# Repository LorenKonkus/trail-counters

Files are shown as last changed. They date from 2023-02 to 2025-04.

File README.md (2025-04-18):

# trail-counters

Sooner or later, anyone involved in building hiking or mountain biking trails on public lands is faced with questions about their user community. Whether to justify more trails, improvement in existing trails, apply for grants or funding, understand usage patterns, or just bragging rights, everyone likes objective metrics. How many people are using their trails. When are they using it - are there peak times? Are there favorite loops that see a lot more use than other routes? You built it; did they come? 

Really good commercial trail counter systems are available from several companies. These packages are rugged, tested, and well supported but all that comes with a price. A recent survey found sensor prices ranging from $130 to $995 each, most designed as part of an overall system requiring the purchase of proprietary  hardware and ongoing software subscriptions for data collection and analysis from these sensors. If you've got the budget for this, there are several solid choices in that market. Go for it - read no further.

For the nonprofit trail advocacy groups I work with, an investment of a few thousand dollars to get started has always felt like a lot of money for just data. Stripped to its core, this is a simple task: detecting the presence of a user and recording that event in a time stamped log file. You don't need specialized analysis software. Standard spreadsheet programs are really good at crunching dates and times and making pretty graphs. Once you have event information you can import it and cut and slice it anyway that you'd like for presentation. You do need sensors and data collection hardware, but all the basic building blocks are readily available off the shelf and inexpensive, and that means you can use them in more places. You need to be very careful siting and securing a $500 sensor asset, but you can be a lot more casual about placing a $40 counter. 

That's the theme of this repository: removing the cost barriers by sharing ideas, hardware references, and code to make it easy to create low-cost trail counters for anyone who's interested in trail advocacy.

## Roadmap

The following overview documents might be useful:

- SensorOverview.md - an overview of the types of sensors commonly in use
- PackagingOptions.md - an overview of the ways I've packaged up hardware for field deployments
- HelpfulReferences.md - pointers to docs, videos, and commercial trail counter systems

Along this path, I've built several trail counters to test new ideas and refine the technology. These are:

- UnoCounter - an Arduino UNO based trail counter that records trail usaage event data on an SD card.
- ThriftyCounter - a minimal Adafruit M0 Adalogger feather based counter that records trail usage data on a microSD card. The primary goal was low power usage to minimize battery cost and size for extended unattended operation.
- NiftyCounter - a ThriftyCounter with a user interface based on the Adafruit ESP32-S2 Reverse TFT Feather. 
- NiftyCounterSTHS34PF80 - a NiftyCounter variant designed for an I2C based sensor. 

In addition to these trail counters, there's a small app that harvests trail usage information from Strava each day. Sometimes it's interesting to compare this information to actual counts, and it can be useful to gather information for more trail segments where it's impractical to host actual trail counters. Strava only tracks a small percentage of actual trail use, and so some sort of statistical local multiplier should be applied to get closer to true trail usage. 

- HarvestStrava - harvest segment usage data from Strava.

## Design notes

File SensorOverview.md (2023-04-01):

# Sensor Types

Sensor type and placement are the keys to accurate and correct counting of trail users. Commonly used sensors
are:
- Infrared
- Seismic
- Microwave
- Inductive Loop
- Ultrasound
- Pneumatic

Each has their advantages and disadvantages, but if you can obtain a logic level signal from a sensor when a trail user passes you can 
interface to it and count it.

It should be noted that none of these sensors is totally accurate. A sensor may not be able to distinguish between one hiker and two walking abreast. 
It may not be able to accurately count mountain bikers riding fast in a close cluster, as during a race event. Some sensors may be sensitive to 
the types of clothing being worn. A poorly placed sensor may count individual legs for footfalls. For these reasons, it's best to locate sensors in 
locations that minimize these potential errors:

- Place a sensor in a narrow constriction, as when a trail passes between two large trees or on a narrow bridge where traffic is naturally single file 
- Locate sensors after trail speed calming features, such as tight corners, narrow chicanes, or at the top of a steep climb to minimize issues with rapidly moving users
- Aim sensors at the torso of the typical trail user, not at head height or leg height

It may be possible to differentiate trail users based on sensor choice and positioning. For example, an active infrared sensor 8' off the ground would 
likely be tripped by an equestrian, but not a biker or hiker. An inductive loop would probably detect a bike, and maybe horseshoes, but not a hiker. 

When choosing a sensor strategy, one of the most important considerations will be power consumption. There are a number of really fine, accurate human presence
sensors but some of their power requirements make them really only suitable for line power applications or when large capacity batteries are employed.

## Active Infrared

to be written

## Passive infrared (PIR)

Passive Infrared sensors detect changes in received infrared radiation when a warm body, like a human or a horse, passes by the sensor. Since infrared 
radiation is light, these sensors can use lenses to control the range and detection area of a sensor.

These sensors are typically packaged as a group of one or more sensors and electronics that compares changes in the IR light detected by these sensors. Changes
are interpreted as motion and a digital logic output pulse is generated.

### Characteristics of PIR Sensors

- Because these sensors are detecting light, they must physically be open to the environment. Any environmental shielding must be transparent to IR radiation
- Many of the PIR sensors are wide field, intended for detecting movement within a room for instance. This is a consideration when siting, as we want to
detect only a single user at a time.
- PIR sensors can sometimes detect swaying branches, so try to site in an area away from shrubbery or low hanging branches that may be impacted by wind.
- PIR sensors can be overwhelmed by bright sunlight, and so try to site in an area with consistent shade. 
- Since PIR sensors do not requre emitting light or radiation, they can be much more energy efficient than active IR or microwave sensors.

### The HC-SR501 PIR Sensor

While there are many PIR sensors, this is a pretty convenient inexpensive package that is readily available. It includes a weatherproof IR transparent
shield (that conveniently fits in a 7/8" hole cut in an enclosure) and has potentiometers to control sensitivity and retrigger delay times. It's power efficient, requiring only about 50 ua and happily runs on either 5v or 3.3v sources so it's easy to power.

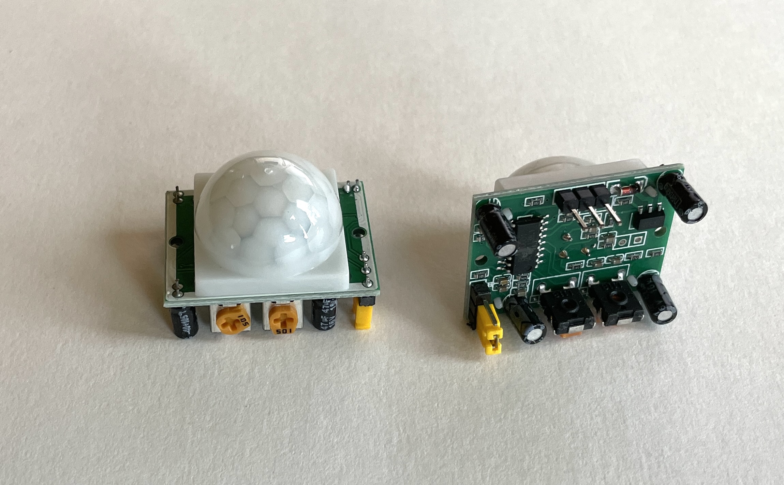
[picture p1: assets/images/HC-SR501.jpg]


I've found that setting the jumper for repeat triggering, the sensitivity to minimum, and the time delay to a minimum value yields the best results. Even then, the minimum time delay value may be too long for fast traffic. Still investigating. 

You can drill a 7.8 inch hole in a waterproof plastic enclosure so that the sensor lens is exposed to IR radiation while protecting the electronics and battery.

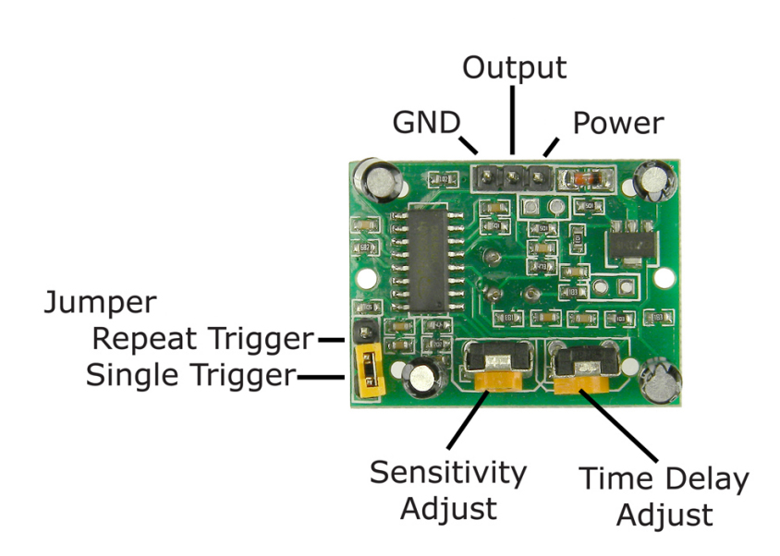
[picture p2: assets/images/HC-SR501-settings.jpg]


HC-SR501 sensors are available here: https://www.amazon.com/DIYmall-HC-SR501-Motion-Infrared-Arduino/dp/B012ZZ4LPM and at many other sources.
 
## Seismic

Seismic sensors work by sensing vibrations, and characterising how those vibrations may map to trail users. Seismic sensors are often mounted to structures 
such as bridges to detect footsteps.

### The LSM303AGR Sensor

The LSM303AGR chip is a low power, high sensitivity accelerometer and magnetometer package that has been used in a number of trail counter packages. 

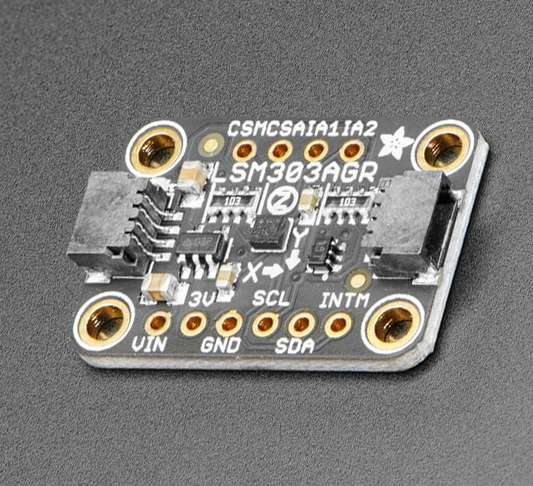
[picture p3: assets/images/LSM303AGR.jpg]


These modules are available from a number of sources. I'm using the breakout board available at https://www.adafruit.com/product/4413

(more coming soon as I gain more experience with it)

## Microwave

Microwave sensors work by broadcasting a low power microwave signal and listening for an echo. That signal is reflected strongly by water, and by 
happy coincidence humans are mostly water. Any change in the dopler shift of the received echo denotes movement, and movement and echo strength over a
certain level can be used to determine the presence of a nearby user. Sounds complicated, but all this has been figured out and bundled up in convenient 
inexpensive packages ready for use.

### Characteristice of microwave sensors

- Microwaves can pass through some solid materials such as wood. This means that a trail counter could be embedded inside a 4x4 wooden signpost next to a trail 
or located on the underside of a bridge plank and be complerely clandestine.
- Microwave sensors are affected by nearby metal, and so cannot be enclosed in a metal vandal resistent case or attached to a metal fencepost, for instance. 
- Microwaves seem less effective during rainstorms
- Microwave sensor operation is unaffected by bright sunlight, moving shadows, the darkness of night, or headlights on bikes.

### The RCWL-0516 sensor

This is a powerful yet inexpensive sensor, but a little hard to tune and senstive to surroundings. Tuning trigger and retrigger times means soldering SMD 
components. Still, it's my go-to for a microwave sensor. It's power efficient, requiring only about 1.2 ma and happily runs on either 5v or 3.3v sources so it's easy to power up in the field with batteries or solar. The output signal can be used directly as a logic input to a trail counter. 

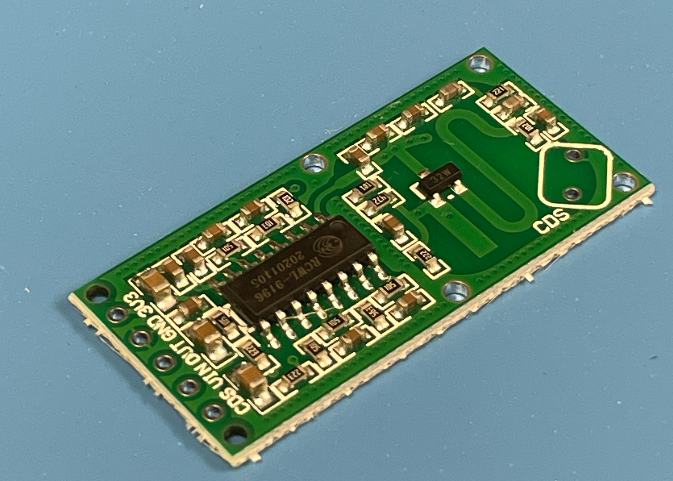
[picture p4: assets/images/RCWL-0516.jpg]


These modules are available at https://www.amazon.com/gp/product/B07YYY7J7D

There's alot of tuning and usage information at https://github.com/jdesbonnet/RCWL-0516 - see especially the issues discussions.

By default, these sensors have about an active high trigger time of 2 seconds and a low retrigger time of 2 seconds between detection events. This isn't optimal for detecting individual riders in a group of mountain bikers, so I generally modify these boards to lessen that. 

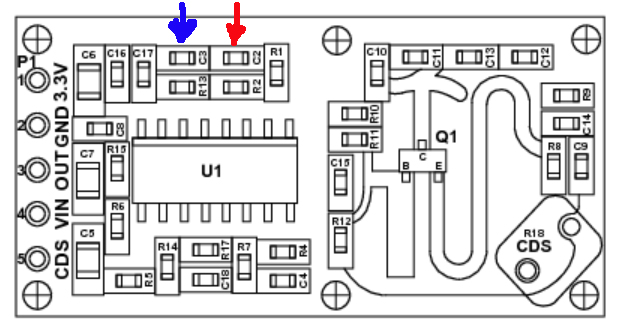
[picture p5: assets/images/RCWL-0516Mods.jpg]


You can replace C2 (in red) with a smaller capacitor for a narrower trigger pulse time and you can replace C3 (in blue) with a smaller capacitor for a shorter retrigger time between pulses. Replacing both with .001 uf results in a minimum output pulse duration of about 300 ms and a minimum time between pulses of about 300 ms which works pretty well differentiating fast moving bike traffic.

### The HFS-DC06F sensor

This is a really nice, stable sensor package with easily adjustable range and trigger time settings. The output signal can be used directly as an 
input to an Arduino Uno counter. The only downside to this package is that it's a bit of a power pig, requiring 30ma at 5 volts in operation. Given 
that, it does work well as a detection sensor if you turn down the range and trigger time settings to their minimal values. This will result in a workable range of about 6 feet and about 2 seconds of high signal for each detection event. This is fine for hikers and relatively slow low volume bike traffic where users are 4 seconds apart, but may undercount if they are closer together than that.

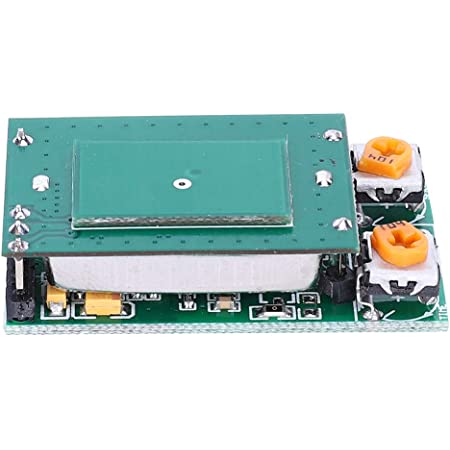
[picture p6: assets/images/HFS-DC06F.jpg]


These modules are currently available at https://www.amazon.com/gp/product/B08TMQ36H6 or shop around.

## Inductive Loop

to be written

## Ultrasound

to be written

## Pneumatic

to be written

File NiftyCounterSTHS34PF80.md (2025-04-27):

# NiftyCounterSTHS34PF80

NiftyCounterSTHS34PF80 is a derivitive of the NiftyCounter with code updated to work with an ST Microelectronics STHS34PF80 TMOS motion and presence sensor
on an I2C bus and separate interupt input. 
With this sensor, the Adafruit ESP32-S2 (or -S3) Reverse TFT Feather microcontroller waits for an interupt and then communicates with the sensor to determine 
presence or motion within its field of view, records each trail user detection event as an entry in a .CSV file on a 
microSD card that can be collected and imported into a spreadsheet. 

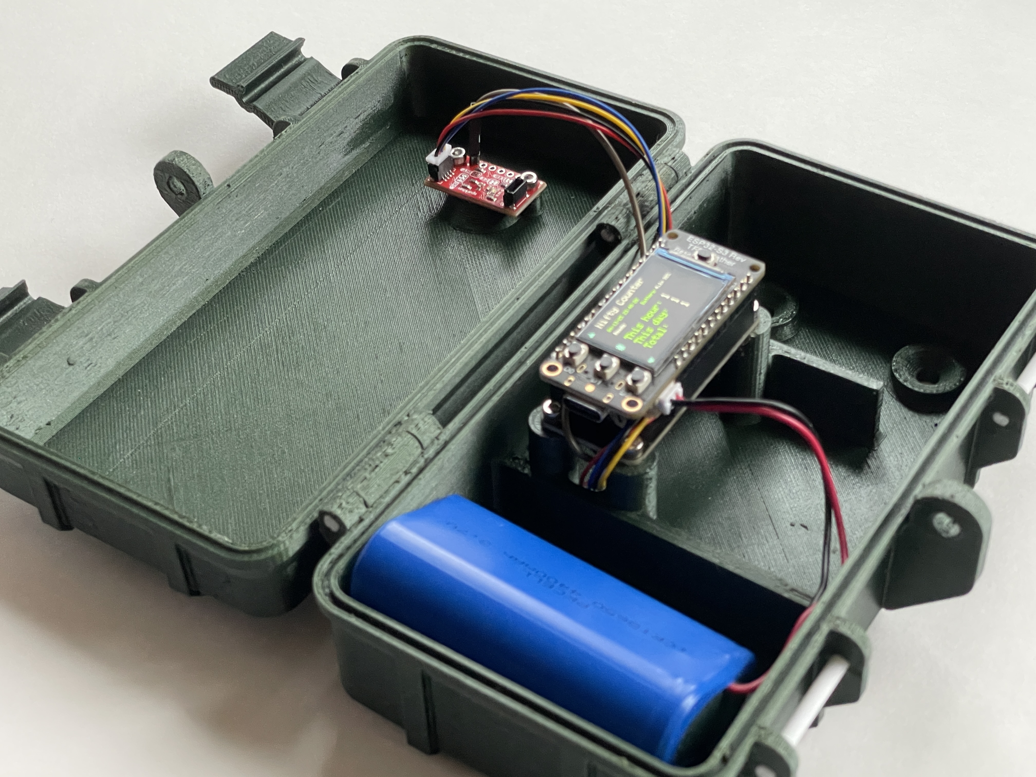
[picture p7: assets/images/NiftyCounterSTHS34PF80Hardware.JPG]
NiftyCounter assembled


## Hardware Platform

NiftyCounterSTHS34PF80 is based on an Adafruit ESP32-S2 Reverse TFT Feather board, available at https://www.adafruit.com/product/5345 Alternately, it seems to run just fine on the -S3 variant as well, so use whatever is available.

The Reverse TFT Feather board includes the processor, a nice 240x135 TFT display with three buttons, a LiPo battery charger, WiFi, and other features we don't need (and will keep turned off to save power). 
The ESP32-S2 on this board is different than the processor on the NiftyCounter board, but it too is supported by the Arduino IDE development environment
so it was pretty straightforward to migrate the NiftyCounter code to this platform. This processor has much more memory and processing power available, so there's
room to code up a nice user interface and expand features in the future.

Like the ThriftyCounter, the LiPo battery support on this board opens up a number of possibilities in power  management. If USB power is available, the adalogger board will 
automatically use that power source and charge an attached LiPo battery. If the USB power is lost, the adalogger board uses the LiPo battery as a source. 
This means you could use a cheap USB solar panel charger to power it during the day and keep the LiPo battery topped off, or periodically plug in an external USB
battery pack to top off an internal LiPo battery. Or just swap the LiPo battery when you're swapping the microSD card each month. 

In addition to the ESP32-S2 feather board we'll need to add data recording and a battery backup real time clock. Adafruit has one of these at
https://www.adafruit.com/product/2922 that works nicely and can stack on the Reverse TFT Feather Board

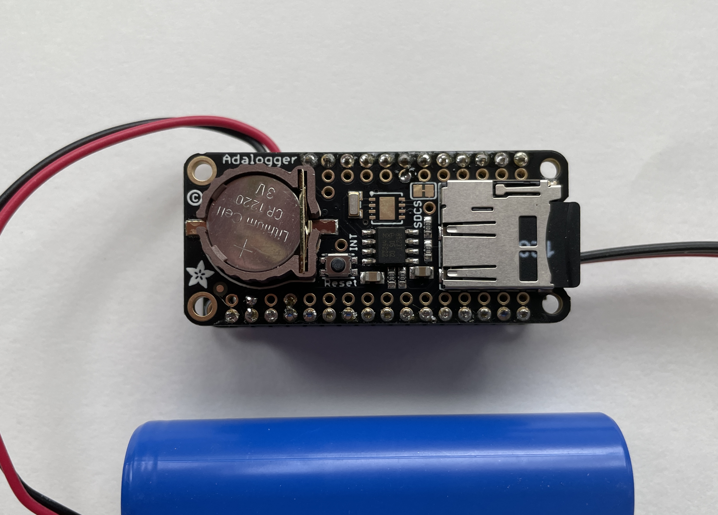
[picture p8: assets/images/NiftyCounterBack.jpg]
NiftyCounter assembled


As I mentioned, the ESP32-S2 contains WiFi support, and the -S3 variant includes BLE as well. It would be possible to enable one of these and remote harvest
counter data without touching a counter, but there's two big issues with this:
- Power consumption.
- Counter Discovery. Broadcasting a signal makes a counter huntable by nefarious foreign agents.

It would be possible to code a button or menu option to turn on communications for a short period to harvest data, but that means having access to the counter and if 
you're there it's so much easier to just swap the microSD card. 

## Software Platform

The NiftyCounterSTHS34PF80 software can be found in NiftyCounterSTHS34PF80.ino in this repository. Well, it will be as soon as I'm happy enough 
with the software to share.

## Sensor

The NiftyCounterSTHS34PF80 software was designed for the ST Microelectronics STHS34PF80 TMOS motion and presence sensor, available at https://www.sparkfun.com/sparkfun-mini-human-presence-and-motion-sensor-sths34pf80-qwiic.html

See [Sensor Overview](SensorOverview.md) for more information on sensors.

## Using the NiftyCounterSTHS34PF80

On startup, the display, clock, and SD card are initialized and readied. Users can follow along on the startup log

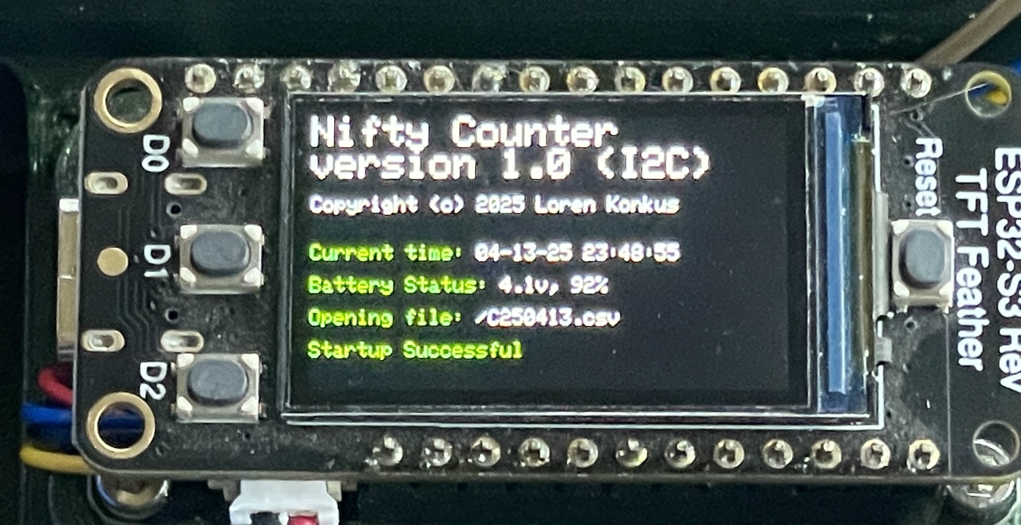
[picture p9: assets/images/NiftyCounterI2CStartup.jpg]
NiftyCounter assembled


After a moment or two, the normal main dashboard is displayed. This dashboard includes information about the current time, battery status, sensor status, and count
values for the hour, day, and since last startup.

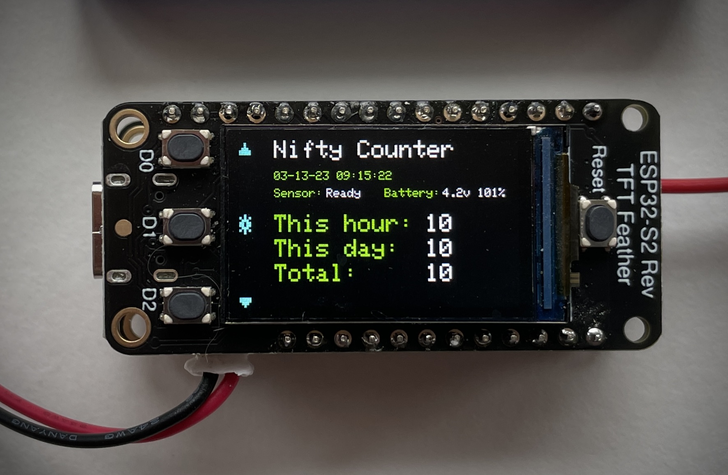
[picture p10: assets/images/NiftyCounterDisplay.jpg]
NiftyCounter assembled


The display remains visible for a few moments, and then is turned off to save power. Pressing any button on the left will reactivate the display again. 

Pressing the middle (D1) button will display the options menu:

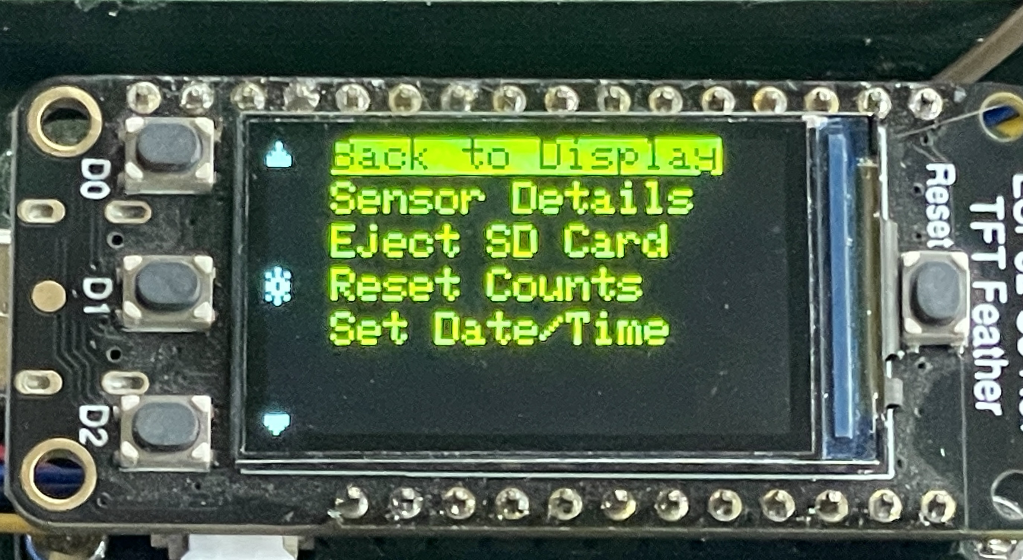
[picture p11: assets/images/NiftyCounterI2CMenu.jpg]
NiftyCounter assembled


These menu options can be used to select various features - debugging sensors, safely ejecting the microSD card, etc. D0 is the up button, D2 the down button, and D1
selects/enters. 

Selecting the Sensor Details menu option will display a dynamic page displaying position and motion sensor values. Highlighted reverse text indicates that the values are at the level
that would be considered "active":

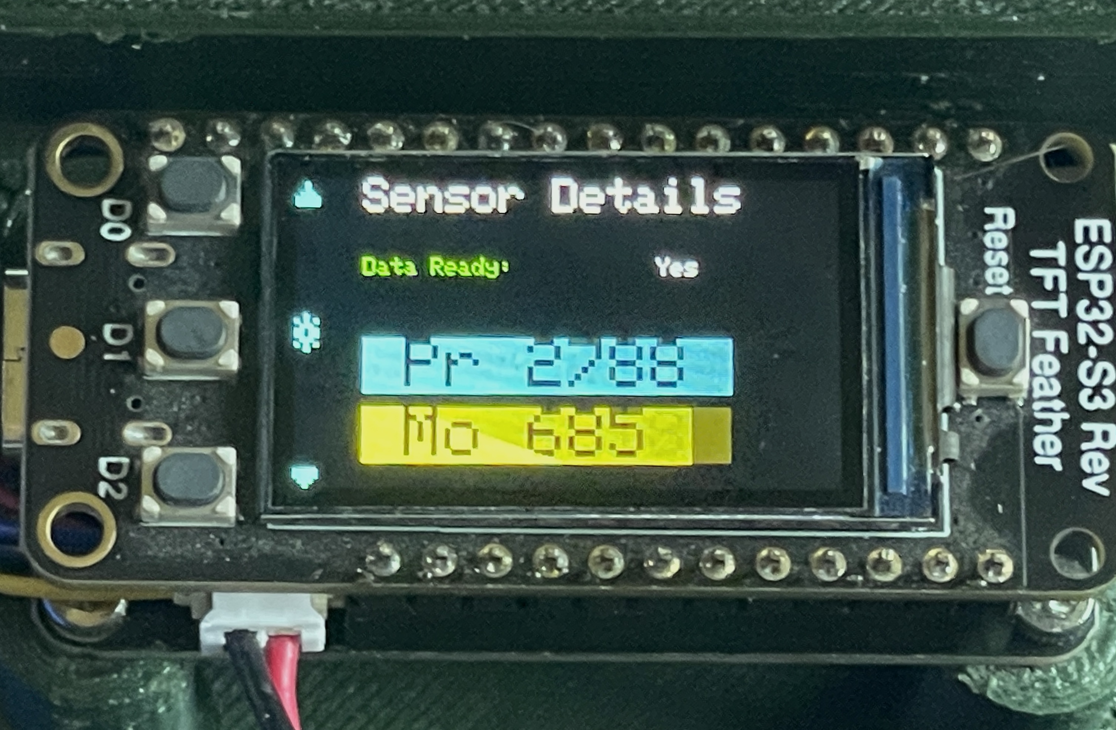
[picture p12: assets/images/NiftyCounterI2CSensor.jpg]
NiftyCounter assembled


To harvest data, simply select "eject SD card" in the menu, replace the microSD card with a new, preformatted card and press the board Restart button. The SD 
card will contain a .csv file named "CYYMMDD".csv, where YYMMDD reflect the current date. Each entry in the csv file will contain fields for the timestamp of 
the event, the date of the event, the time of the event, the duration of the event, and an event count.

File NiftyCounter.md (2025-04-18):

# NiftyCounter

NiftyCounter is an Adafruit ESP32-S2 (or -S3) Reverse TFT Feather based trail counter that records each trail user detection event as an entry in a .CSV file on a 
microSD card that can be collected and imported into a spreadsheet. 

NiftyCounter was developed as a followup to the ThriftyCounter project. ThriftyCounter works pretty well and has been counting trail users for some time, but there
was room for improvement.

- There's no way to determine if someone is looking at it or not, and so the green LED is faithfully lit every time a user detection sensor is active. This takes
about 11 ma the entire duration that a user is present. It's not a lot, but it adds up over time. 
- It's an act of faith that the RTC clock battery is good and the date and time is correct when you deploy a counter
- There's no way to determine that the LiPo battery is low and needs to be replaced or recharged

As it turns out, for only an additional $10 or so you can add a very nice user interface to this design, and a user interface can address each of these
shortcomings. Hence, the NiftyCounter was created.

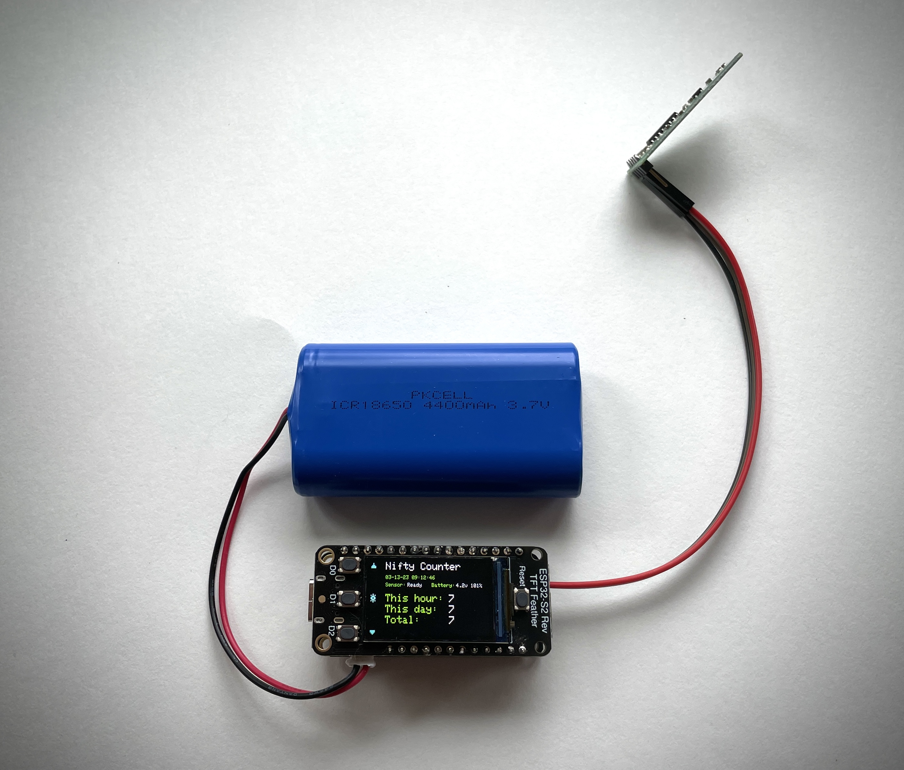
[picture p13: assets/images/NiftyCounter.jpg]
NiftyCounter assembled


## Hardware Platform

NiftyCounter is based on an Adafruit ESP32-S2 Reverse TFT Feather board, available at https://www.adafruit.com/product/5345 Alternately, it seems to run just fine on the -S3 variant as well, so use whatever is available.

The Reverse TFT Feather board includes the processor, a nice 240x135 TFT display with three buttons, a LiPo battery charger, WiFi, and other features we don't need (and will keep turned off to save power). 
The ESP32-S2 on this board is different than the processor on the NiftyCounter board, but it too is supported by the Arduino IDE development environment
so it was pretty straightforward to migrate the NiftyCounter code to this platform. This processor has much more memory and processing power available, so there's
room to code up a nice user interface and expand features in the future.

Like the ThriftyCounter, the LiPo battery support on this board opens up a number of possibilities in power  management. If USB power is available, the adalogger board will 
automatically use that power source and charge an attached LiPo battery. If the USB power is lost, the adalogger board uses the LiPo battery as a source. 
This means you could use a cheap USB solar panel charger to power it during the day and keep the LiPo battery topped off, or periodically plug in an external USB
battery pack to top off an internal LiPo battery. Or just swap the LiPo battery when you're swapping the microSD card each month. 

In addition to the ESP32-S2 feather board we'll need to add data recording and a battery backup real time clock. Adafruit has one of these at
https://www.adafruit.com/product/2922 that works nicely and can stack on the Reverse TFT Feather Board

NiftyCounter assembled

As I mentioned, the ESP32-S2 contains WiFi support, and the -S3 variant includes BLE as well. It would be possible to enable one of these and remote harvest
counter data without touching a counter, but there's two big issues with this:
- Power consumption.
- Counter Discovery. Broadcasting a signal makes a counter huntable by nefarious foreign agents.

It would be possible to code a button or menu option to turn on communications for a short period to harvest data, but that means having access to the counter and if 
you're there it's so much easier to just swap the microSD card. 

## Software Platform

The NiftyCounter software can be found in NiftyCounter.ino in this repository.

## Sensor

See [Sensor Overview](SensorOverview.md) for more information on sensors.

I used RCWL-0516 microwave sensors when using this trail counter. These sensors can be powered directly from the board (using the GND and 3.3V pins 
and the output logic signal can be tied to one of the input pins (I used DIO 11 in the software). This sensor works best when located a couple inches 
away from the feather boards and battery, with no metal or electronics directly in front or behind the antenna area on the sensor board.

The data sheets for the RCWL-0516 say that the board requires an input voltage between 4 and 28v, but that input is regulated to 3.3 volts to run board and the
samples that I've used seem totally happy running with the nice, clean, regulated 3.3v source that the adalogger feather can provide.

## Using the NiftyCounter

On startup, the display, clock, and SD card are initialized and readied. Users can follow along on the startup log

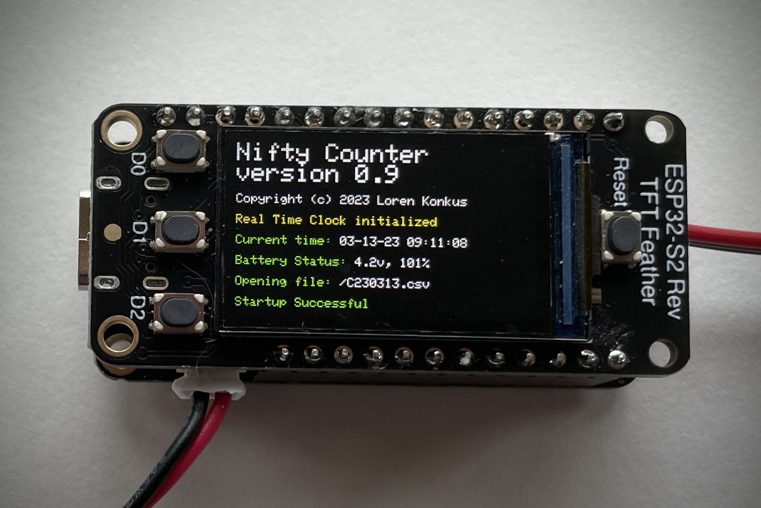
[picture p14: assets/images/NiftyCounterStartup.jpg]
NiftyCounter assembled


After a moment or two, the normal main dashboard is displayed. This dashboard includes information about the current time, battery status, sensor status, and count
values for the hour, day, and since last startup.

NiftyCounter assembled

The display remains visible for a few moments, and then is turned off to save power. Pressing any button on the left will reactivate the display again. 

Pressing the middle (D1) button will display the options menu:

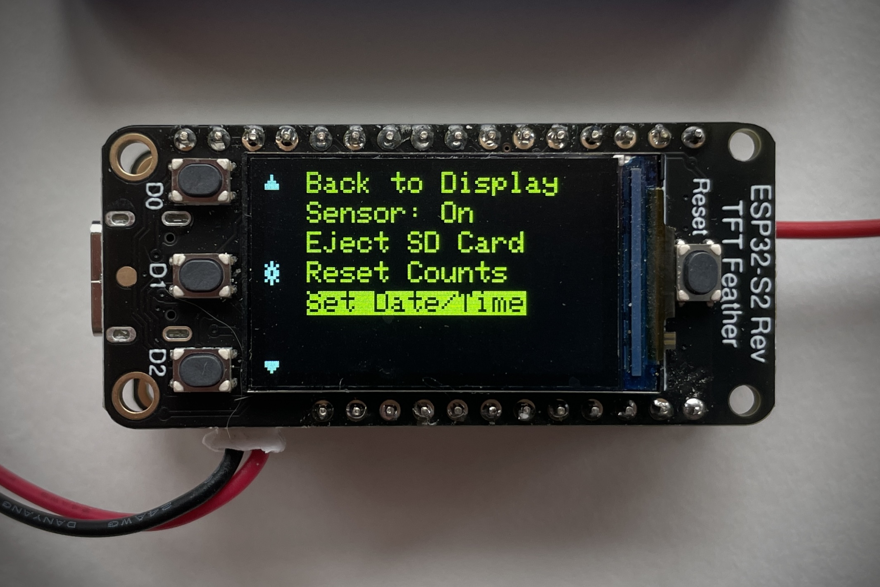
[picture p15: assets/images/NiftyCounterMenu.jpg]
NiftyCounter assembled


These menu options can be used to select various features - disabling sensors, safely ejecting the microSD card, etc. D0 is the up button, D2 the down button, and D1
selects/enters. 

To harvest data, simply select "eject SD card" in the menu, replace the microSD card with a new, preformatted card and press the board Restart button. The SD 
card will contain a .csv file named "CYYMMDD".csv, where YYMMDD reflect the current date. Each entry in the csv file will contain fields for the timestamp of 
the event, the date of the event, the time of the event, the duration of the event, and an event count.

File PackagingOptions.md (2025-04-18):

# Packaging Options

Here are several alternatives I've used for packaging a counter:

- ZipLoc Bag
- ABS Waterproof Box
- 3d Printed Enclosures

## ZipLoc Bag

The simpliest option when deploying a trail counter is to tuck it in a simple ZipLoc bag. These are waterproof, low cost, and easy to locate in small, odd areas. 
Bags are great for quickly deploying a prototype out on the trail. 

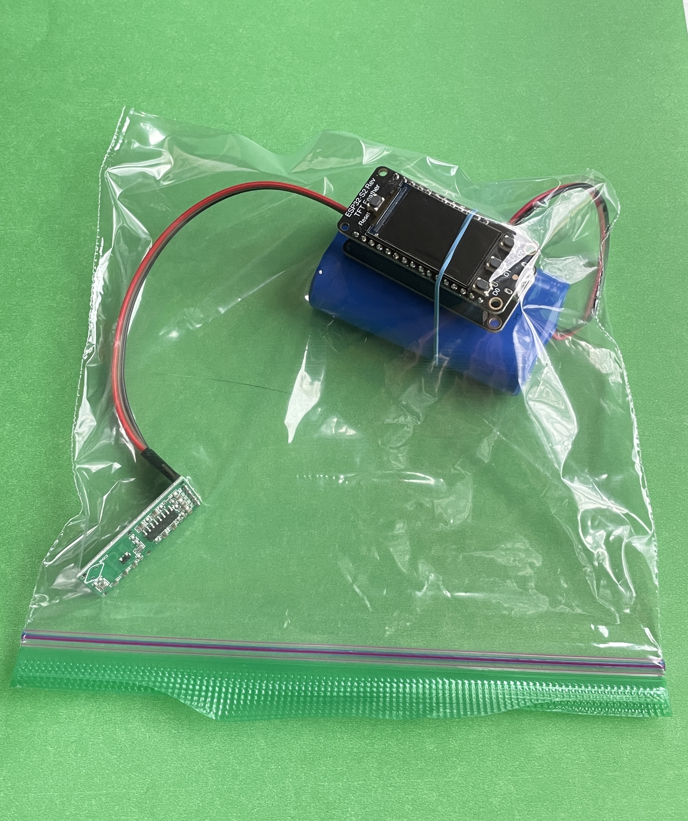
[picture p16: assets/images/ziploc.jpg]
ziploc


On the downside, they aren't particularly robust, are vulnerable to animals, and may be mistaken as rubbish. Some sensors are very sensitive to their surroundings
and may be affected by batteries and controller locations, and that's hard to control in a bag. 

## ABS Waterproof Box

Commercial ABS waterproof junction boxes are solid and robust and available in many sizes and formats. Here's one that I've used.

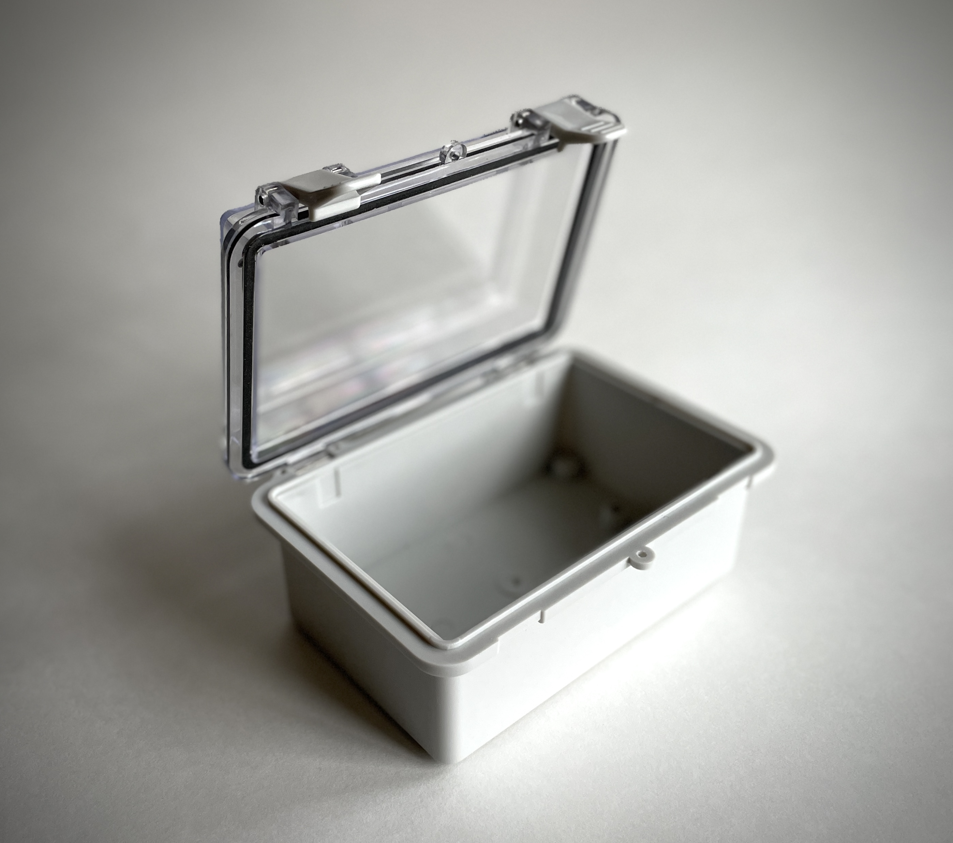
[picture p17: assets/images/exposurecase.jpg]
case


This is relatively small at 6"x4"x3" but sill big enough for an Arduino Uno and is available at https://www.amazon.com/Zulkit-Waterproof-Electrical-Transparent-150x100x70/dp/B07RPNWD47

Being ABS, it's easy to use styrene solvent to glue plastic standoffs wherever needed to mount a circuit board.

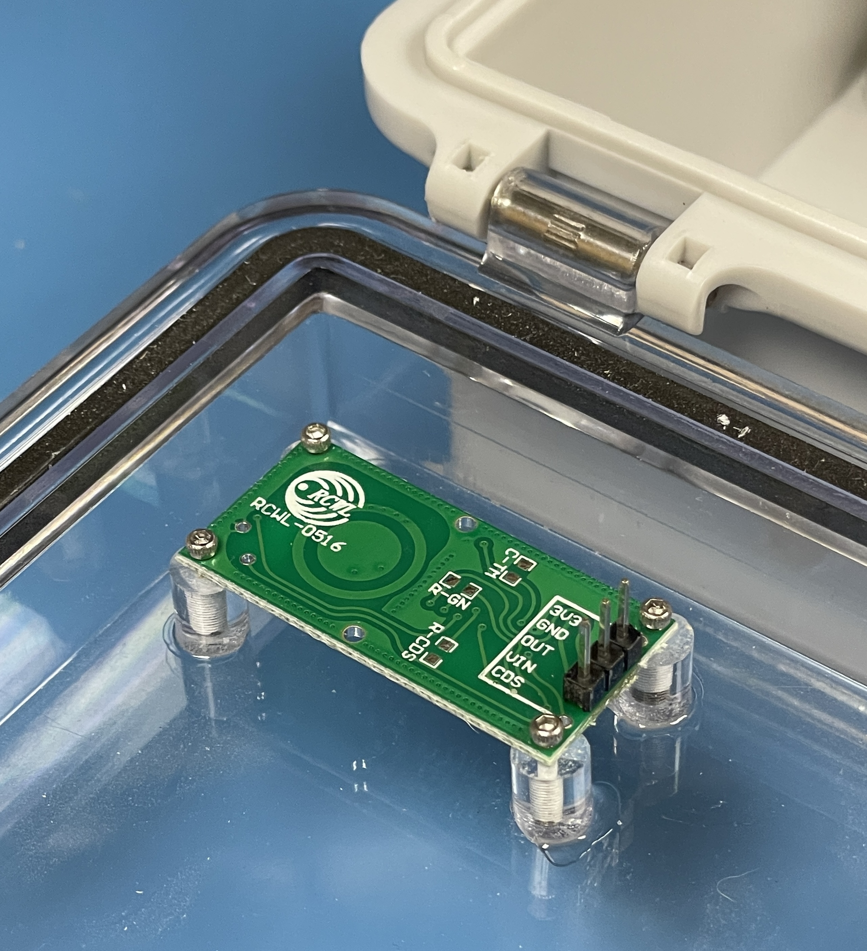
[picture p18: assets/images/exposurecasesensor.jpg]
case

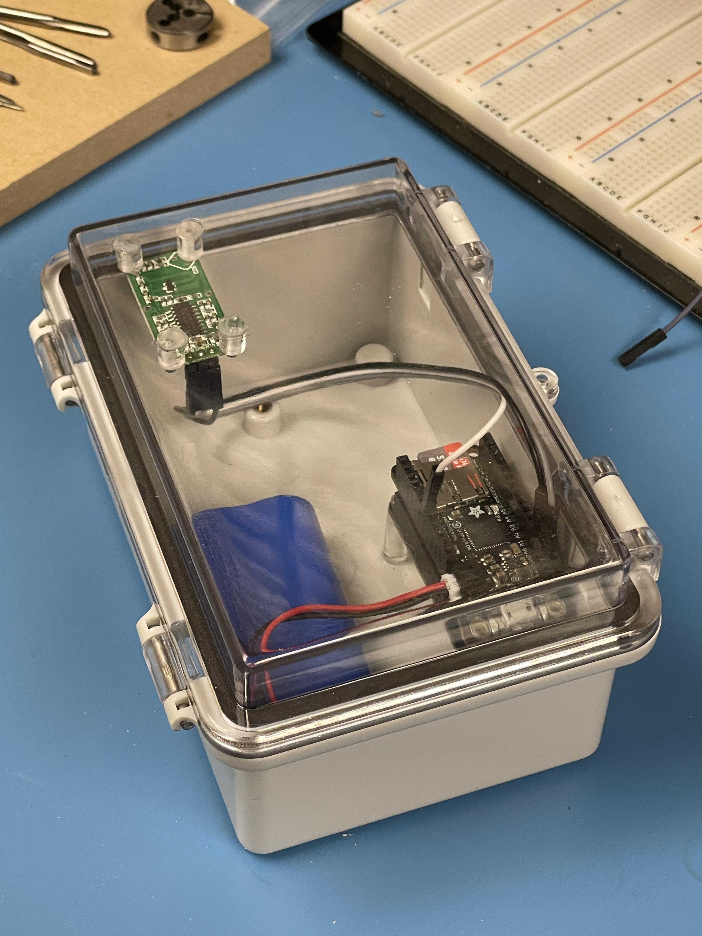
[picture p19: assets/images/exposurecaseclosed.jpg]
case


If you have a transparent cover for the box, boards can be positioned so that LEDs are easily visible to confirm operation after positioning.

If you're using a microwave sensor that can sense presence through wood, one of my favorite placements is on a support beam under a bridge. Narrow bridges encourage
users to pass single file and at relatively slow speeds and help to ensure accurate counts.

case

## 3d Printed Enclosures

### PostIt Frame

The PostIt frame was designed to conceal a feather based trail counter within a 2 inch diameter, 8 inch deep hole bored into a wooden post. 4x4 posts are common
sights along a trail, often festooned with decals and pointers, and are not obvious targets for anyone looking for a trail counter. This design relies on the 
post for environmental protection, and can only be used with sensors that can detect presence through wood (like a microwave sensor). 

case

The basic design is a cylinder with space for a 4400 mah LiPo battery at the bottom, a stack of two feather boards, and space for a sensor at the top. It's open to allow access 
to the front and back of a feather stack to replace the battery, plug in a USB cord, and swap microSD cards without removing any boards from the frame. There's a 
recess for a rubber band to hold the battery at the bottom, and a finger hold at the top to ease extraction from a post. (Or you can tie a lanyard to it so it's easier to retrieve from a deeper bore.) The cylinder is 1.75 inches in diameter which provides lots of clearance in a 2 inch bore in a post. 

This frame can hold components for either the ThrifyCounter or NiftyCounter. Here's what it looks like with NiftyCounter components mounted:

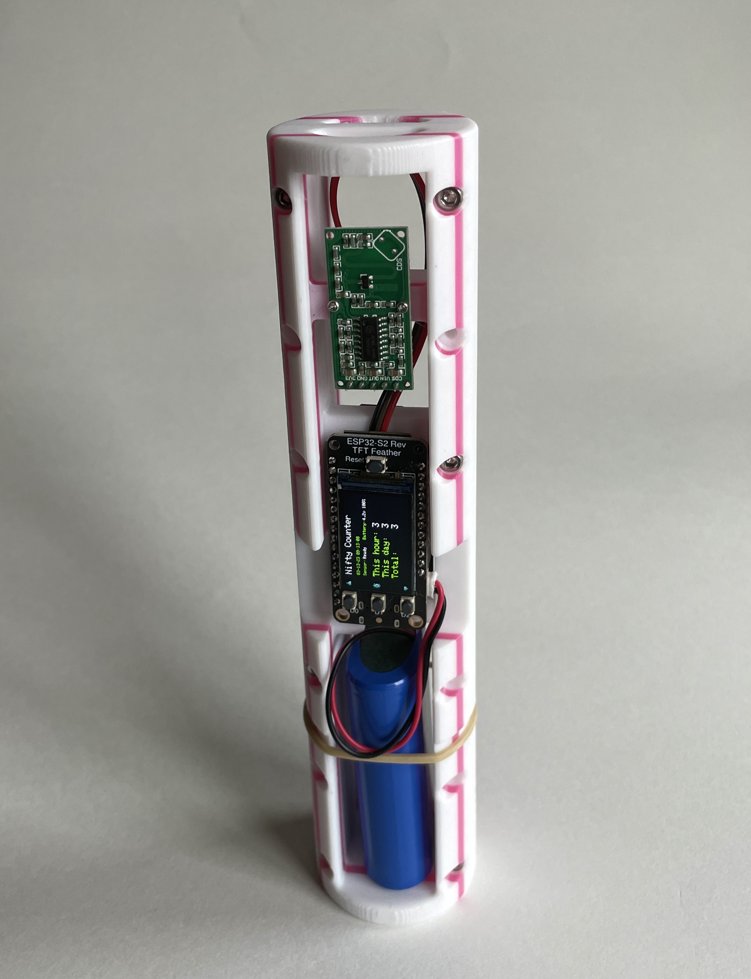
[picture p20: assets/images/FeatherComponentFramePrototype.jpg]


The STL file for the PostIt frame can be found in the repository at PostIt.stl. When 3d printing, it's easiest to print in two sections, front and back, to eliminate
issues with horizontal spans and avoid the need for bridging or supports. These sections can either be glued together or assembled using 2.5 mm machine screws. 
You can find a two part version at PostItSplit.stl. 

The model has tap holes for a RCWL-0516 microwave sensor (mount with 1.4 mm machine screws) and tap holes for feather boards (mount with 2.5 mm machine screws). You
might need to tweak this somewhat when using different sensors.

### NiftyCase Box

The NiftyCase box was designed to house a feather stack, some sort of infrared or visual detector, and a battery in a case that could be screwed to a 4x4 post or a tree. 

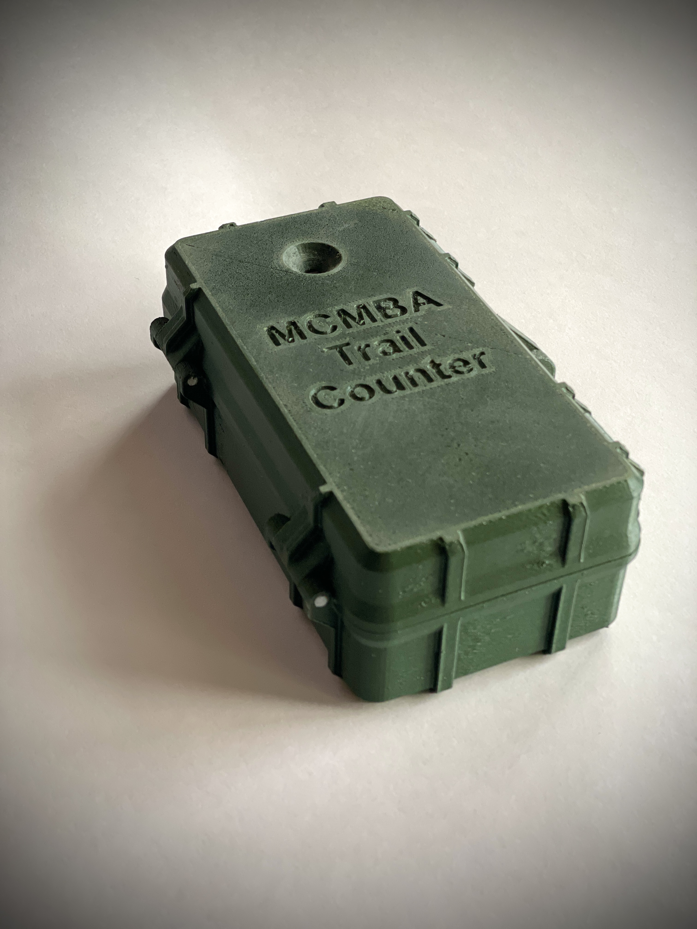
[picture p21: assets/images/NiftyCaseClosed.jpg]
case

case

This frame can hold components for either the ThrifyCounter, NiftyCounter, or NiftySTHS34PF80. Here's what it looks like with NiftySTHS34PF80 components mounted:

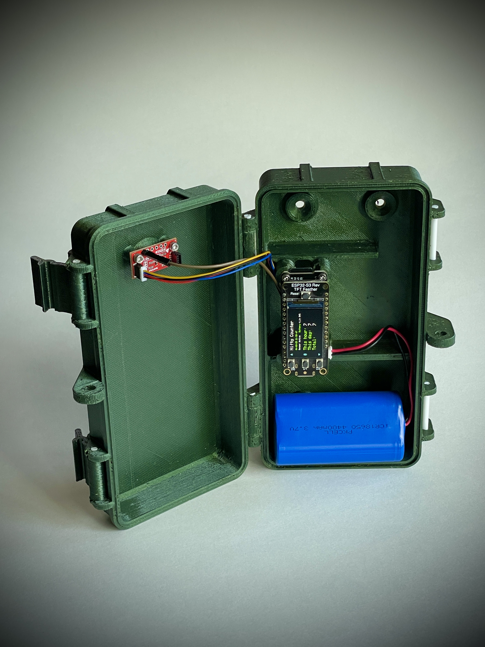
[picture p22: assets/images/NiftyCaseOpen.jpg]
case


There's plenty of space reserved for larger batteries.

The STL files for this can be found in the repository as NiftyCaseBox.stl, NiftyCaseLid.stl, NiftyCaseLatch.stl (two required) and NiftyCaseTPUSeal. Since these are exposed to the elements, select an appropriate material such as PETG or ABS for longevity. The NiftyCaseTPUSeal is an optional flexible gasket that helps to make the box more weathertight, and should be printed in something like TPU. 

## Tagging

Regardless of what package you use, it's good practice to include your name (or your organization's name) and a contact phone number in the package. If the 
package is misplaced, this information may help it find its way home. If it's located by a suspicious individual, a phone call can help the bomb squad determine that 
it's a LiPo battery and not C4.

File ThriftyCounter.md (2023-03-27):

# ThriftyCounter

ThriftyCounter is an AdafruitFeather M0 Adalogger based trail counter that records each trail user detection event as an entry in a .CSV file on a 
microSD card that can be collected and imported into a spreadsheet. ThriftyCounter was developed as a followup to the UnoCounter project in an attempt to 
lower energy usage and improve battery life. An Arduino Uno requires a fair amount of power even when the microcontrolleris in sleep mode, and this
has an impact on the battery required for extended deployment times out in a forest. Batteries are expensive, and if we can halve or quarter the amount
of capacity that we need we can reduce the cost significantly. ThriftyCounter was a great step in that direction. 

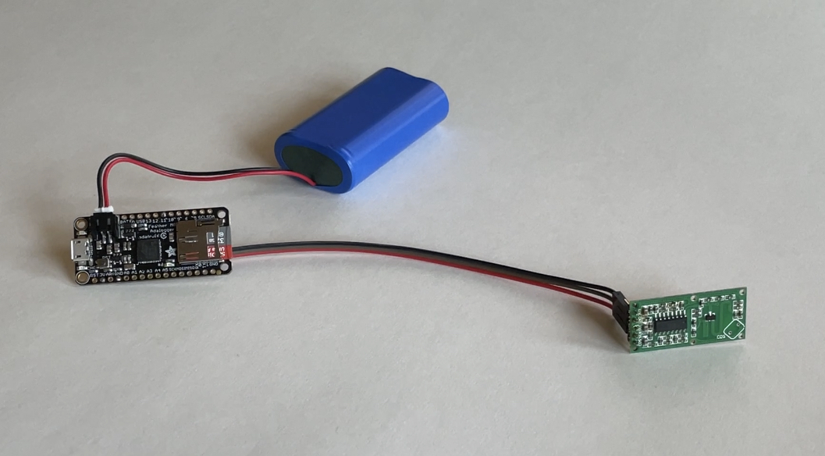
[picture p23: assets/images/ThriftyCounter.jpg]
ThriftyCounter assembled


## Hardware Platform

ThriftyCounter is based on an Adafruit Feather M0 Adalogger board, available at https://www.adafruit.com/product/2796 

In the same way that there's an ecosystem for Arduino Uno boards and shields that add additional capabilities, there's an ecosystem of Feather boards and "wings"
that stack and add capabilities. 

The adalogger board includes the processor, a LiPo battery charger, and a microSD card slot, so it has most of what we need (except a good real time clock - more on that
later). The ARM M0 processor on this board is different than the processor on the Uno board, but it is supported by the Arduino IDE development environment
so it was pretty straightforward to migrate the UnoCounter code to this platform. This processor has more memory and processing power available, and so there's
room to grow if we want to, say, enhance the software to collect data from multiple sensors.

The LiPo battery support on this board opens up a number of possibilities in power  management. If USB power is available, the adalogger board will 
automatically use that power source and charge an attached LiPo battery. If the USB power is lost, the adalogger board uses the LiPo battery as a source. 
This means you could use a cheap USB solar panel charger to power it during the day and keep the LiPo battery topped off, or periodically plug in an external USB
battery pack to top off an internal LiPo battery. Or just swap the LiPo battery when you're swapping the microSD card each month. 

One thing the adalogger board doesn't have is a good real time clock, or RTC. The M0 processor provides an RTC and the software is able to use it as a backup
time source, but any information about the current date and time is lost 
whenever power is lost or the reset button is pressed. Fortunately, there are plug in feather wings that adds a battery backed up RTC. I've used one based on
the DS3231 chip, available at https://www.adafruit.com/product/3028 Plug this wing into the adalogger feather, and it keeps excellent track of date and times 
across battery changes, restarts, and so forth. 

## Software Platform

The ThriftyCounter software can be found in ThriftyCounter.ino in this repository.

## Sensor

See [Sensor Overview](SensorOverview.md) for more information on sensors.

I used RCWL-0516 microwave sensors when using this trail counter. These sensors can be powered directly from the board (using the GND and 3.3V pins 
and the output logic signal can be tied to one of the input pins (I used DIO 11 in the softwear). This sensor works best when located a couple inches 
away from the feather boards and battery, with no metal or electronics directly in front or behind the antenna area on the sensor board.

The data sheets for the RCWL-0516 say that the board requires an input voltage between 4 and 28v, but that input is regulated to 3.3 volts to run board and the
samples that I've used seem totally happy running with the nice, clean, regulated 3.3v source that the adalogger feather can provide.

## Using the ThriftyCounter

This counter has a very minimal user interface that leverages the green and red LEDs on this board on the controller board.

Upon startup, either by inserting a battery or pressing the restart button, the software boots up and attempts to write to the
microSD card. Red LED flashes indicate an issue during startup:

-  2 blinks = error, no RTC clock found
-  3 blinks = error, no microSD card. Insert a FAT32 formatted card to clear condition
-  4 blinks = error, unable to write to a microSD card

After startup, the green LED on the feather is lit whenever the detection sensor is high. The red LED flashes once each time an event
is written to the SD card. Because writing to the SD card is energy intensive, several events may be buffered and written together. 

To harvest data, simply replace the microSD card with a new, preformatted card and press the restart button. The SD card should contain a .csv file
named "CYYMMDD".csv, where YYMMDD reflect the date that the counter was started. Each entry in the csv file will contain fields for the timestamp of the event, the date of the event, the time of the event, the duration of the event, and an event count. 

There's no provision for setting the date and time on the counter. Date and time are updated when the software is downloaded into the controller. The clock should keep accurate time throughout the life of the clock coin battery cell, which should be at least a couple years. At that point, you'll have to change the clock battery and re-load the software again.

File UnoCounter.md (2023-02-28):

# UnoCounter

UnoCounter is a simple an Arduino Uno based trail counter that records each trail user detection event as an entry in a .CSV file on 
an SD card that can be collected and imported into a spreadsheet. It's the first trail counter that I built and deployed to validate the
core project principle: using inexpensive off the shelf hardware components to build a workable counter. And it worked - you can build
this counter by simply plugging things together. 

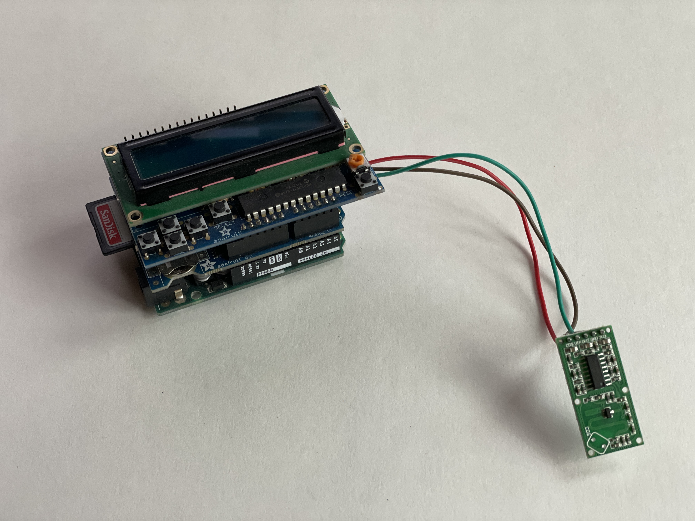
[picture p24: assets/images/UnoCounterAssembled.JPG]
UnoCounter assembled


## Hardware Platform

Ardunino Uno is a ubiquitous platform that is available from many different suppliers and supported by lots of STEM educational kits,
so it makes a good platform for getting started with this technology since you can ask any kid in your local school's robotics club 
for help if you get into trouble. Details on all this can be found at
https://www.arduino.cc/ and there are many really good youtube videos to peruse.

UnoCounter is based on a standard Arduino Uno R3 board and the Arduino IDE development environment. The Uno board contains the microcontroller 
and is where all the software needed to create a trail counter runs. Several companies sell clones of this board or you can buy them on the
arduino site. The official Arduino boards may cost a few dollars more, but helps to support the whole open source infrastructure around this 
technology.

The Arduino Uno ecosystem is populated by a host of supporting "shield" components that can be plugged into, or "stacked" on top of an 
Uno board. One of these shields provides nearly everything we need to support a trail counter: the Adafruit Data Logger shield for Arduino, 
available at https://www.adafruit.com/product/1141  

The Data Logger shield adds two key capabilities to the counter: a Real Time Clock to keep track of the date and time, and a SD card interface
that is used to record events to an SD card which can then be harvested and read by a laptop or computer.

In addition, the UnoCounter software supports an additional shield: an LCD Display Shield, available at https://www.adafruit.com/product/772
If present, this shield adds a handy user interface for testing and verifying your sensor  operation and setup, but really doesn't add any
value to the core mission - logging user detection events - and can be omitted. 

That's it, aside from a battery and a detection sensor. 

UnoCounter Boards

Internally, Arduino Uno boards operate on a 5V supply. You can use any battery capable of providing between 5 and 12 volts to power the stack, 
but the simple linear voltage regulators on these boards aren't terribly efficient and you'll get the best battery life at 5 volts. I've had 
best results with arrays of 4 1.2 volt rechargable NiMH cells. 

## Software Platform

The UnoCounter software can be found in UnoCounter.ino in this repository. 

## Sensor

See [Sensor Overview](SensorOverview.md) for more information on sensors.

I've typically used RCWL-0516 microwave sensors when using this trail counter. These sensors can be powered directly from the board (using the GND and 5V pins 
and the output logic signal can be tied to one of the input pins (I used DIO 3 in the softwear). This sensor works best when located a couple inches 
away from the arduino boards and battery, with no metal or electronics directly in front or behind the antenna area on the sensor board.

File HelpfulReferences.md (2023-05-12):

# Helpful References

A collection of references to documentation and educational materials related to trail counters.

## Trail Counter Education

### American Trails Webinar: Building a Comprehensive Count Program in Your Park or on Your Trails

This webinar will examine real-world count data that illustrates this increased use of trails and 
parks and discuss the logistics and best practices behind building robust count programs at multiple scales. 

https://www.youtube.com/watch?v=d9M9J41m4gI

### IMBA & Eco-Counter – Measuring your impacts and success with trail counters

https://www.youtube.com/watch?v=acs8EINXO14

### USDA Forest Service Revised Guide on Trail Traffic Counters

https://www.fs.usda.gov/t-d/pubs/pdfpubs/pdf99232835/pdf99232835dpi72.pdf

## Commercial trail counter systems

https://www.trafx.net/products.htm

https://www.eco-counter.com/

https://sensmax.eu/solutions/outdoor-people-counters-for-non-electricity-areas/

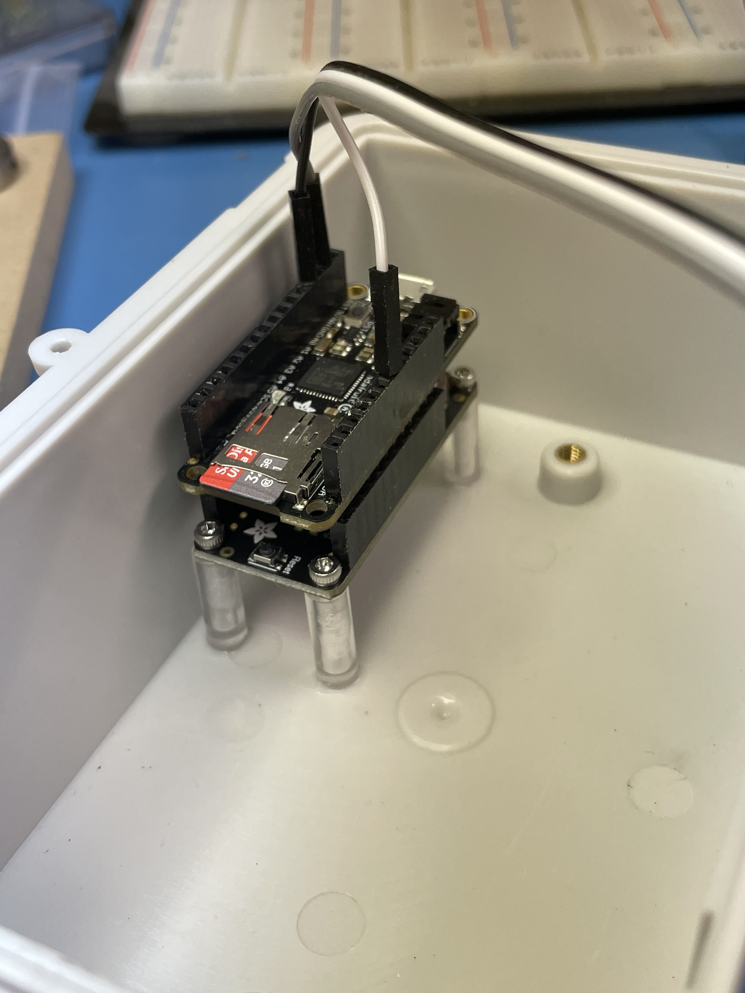
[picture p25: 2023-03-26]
assets/images/exposurecasecontroller.jpg

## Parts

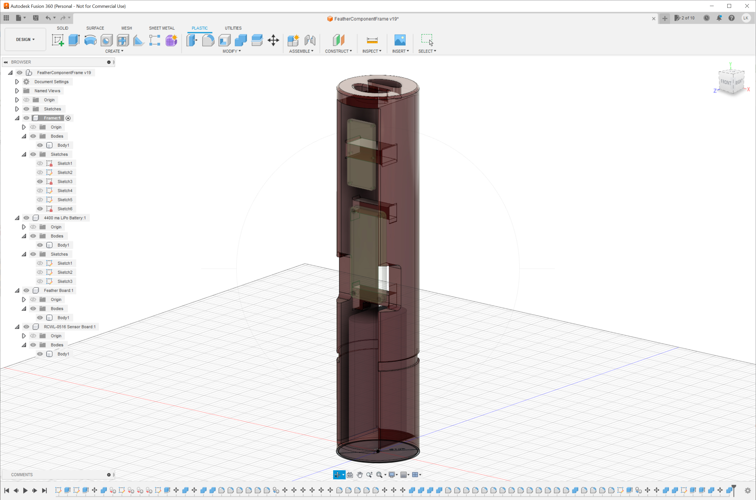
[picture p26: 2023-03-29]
assets/images/FeatherComponentFrameDesign.jpg

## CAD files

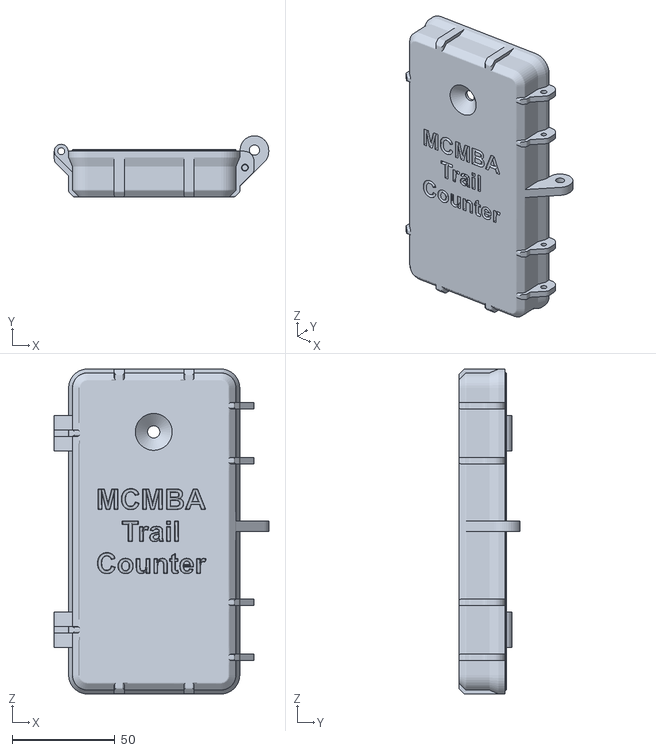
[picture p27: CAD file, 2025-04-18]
NiftyCaseLid.stl
104.6 x 29.9 x 158.5

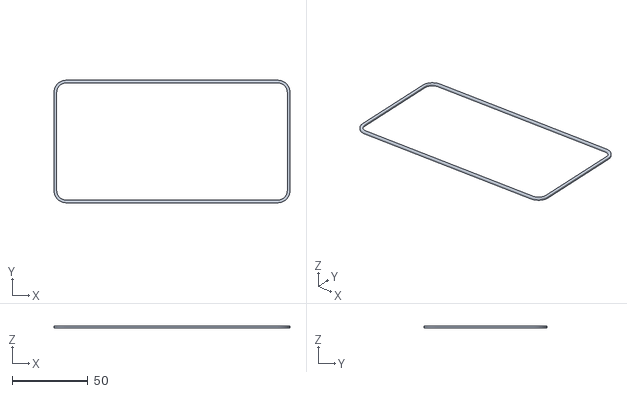
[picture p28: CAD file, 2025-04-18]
NiftyCaseTPUSeal.stl
156.1 x 81.1 x 1.40

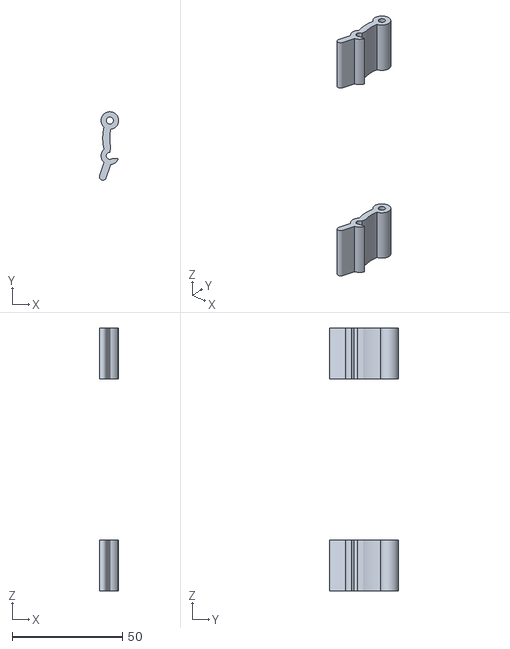
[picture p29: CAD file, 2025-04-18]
NiftyCaseLatch.stl
8.77 x 31.1 x 119.2

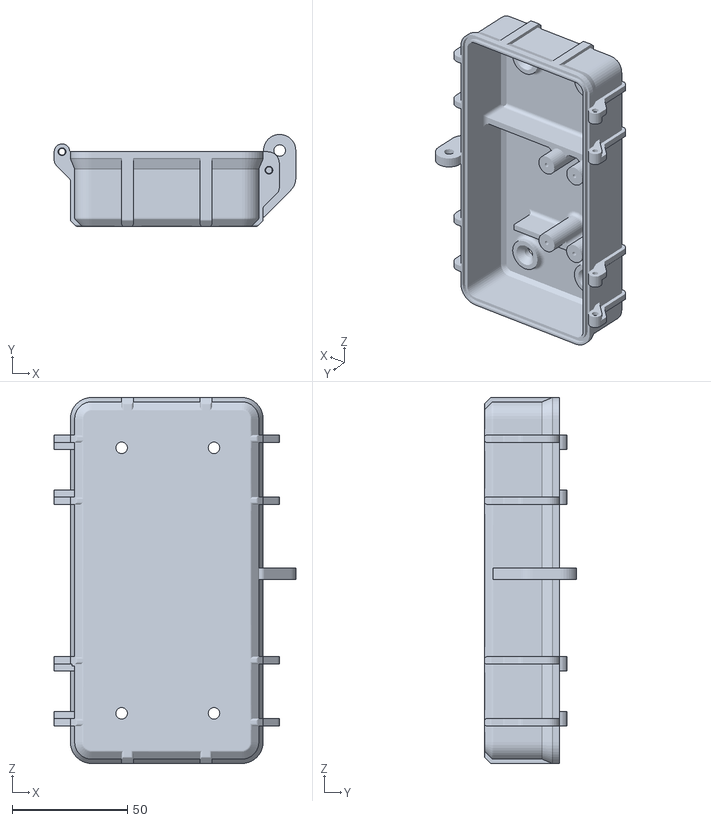
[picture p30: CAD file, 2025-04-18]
NiftyCaseBox.stl
104.7 x 39.9 x 158.5

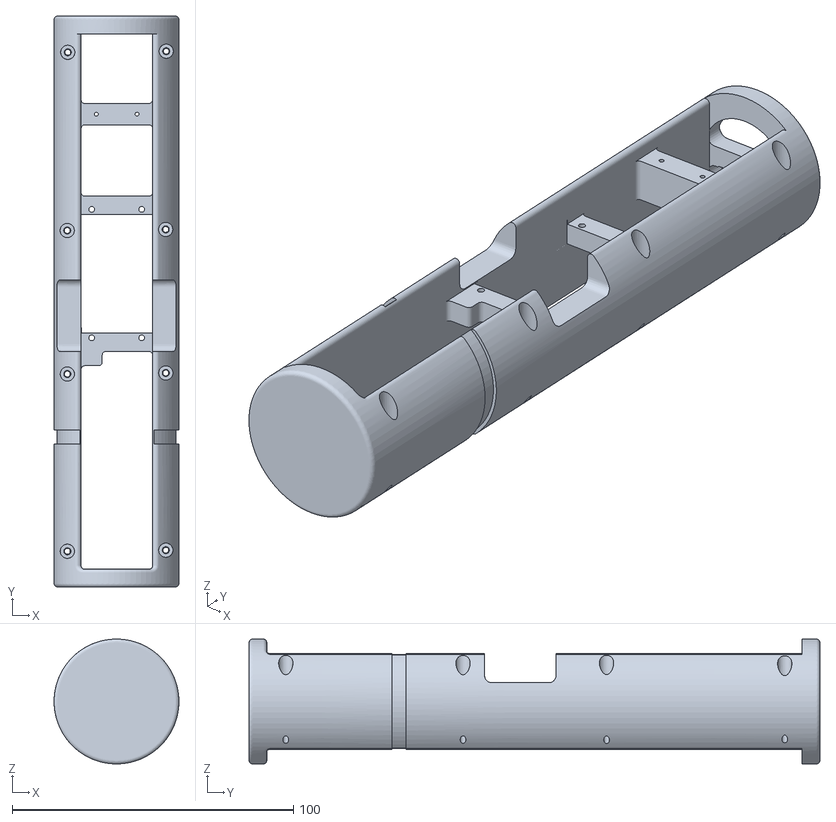
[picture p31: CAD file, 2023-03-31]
PostIt.stl
44.5 x 203.2 x 44.4

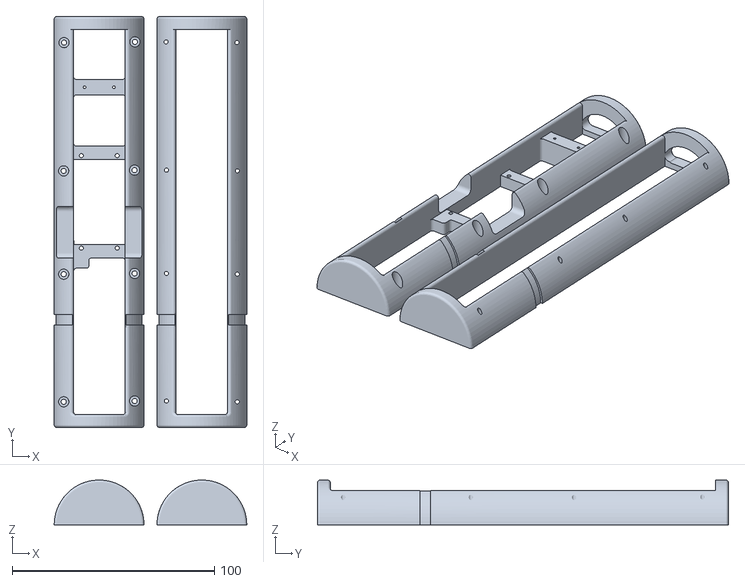
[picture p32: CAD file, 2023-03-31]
PostItSplit.stl
95.3 x 203.2 x 22.2

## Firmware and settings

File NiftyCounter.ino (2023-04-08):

/*
  NiftyCounter - A low cost Trail Counter with a nifty user interface

  A low cost trail use counter using off the shelf hardware and 
  inexpensive, readily available microwave sensors that's appropriate when you
  just want to place a few counters out on trails in the forest and are able
  to visit them every month or two to switch batteries and harvest the microSD card. 

  Required components:
  - adafruit Adafruit ESP32-S2 Reverse TFT feather board
  - adafruit Adalogger feather wing
  - a microwave sensor. Tested using RCWL-0516 and HFS-DC06F, but similar devices should
    work. Really, any sensor that provides a high detection pulse should work.

  Time stamped trail use data is recorded in a .csv file on the SD card that can be 
  viewed and summarized in a spreadsheet. Current trail use statistics can be viewed by
  using the TFT display.

  Copyright © 2023 Loren Konkus
 
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
 */

#include <Adafruit_GFX.h>    // Core graphics library
#include <Adafruit_ST7789.h> // Hardware-specific library for ST7789
#include "Adafruit_MAX1704X.h"
#include <Adafruit_BME280.h>
#include <Wire.h>
#include <SPI.h>
#include <SD.h>
#include "fs.h"
#include "RTClib.h"
#include "driver/rtc_io.h"

// The Adafruit Adalogger board uses a 8523 as the Real time clock
RTC_PCF8523 rtc;

// The Adafruit ESP32-S2 card's buit in Battery monitor
Adafruit_MAX17048 batteryMonitor;

// The Adafruit Reverse TFT card's built in display
Adafruit_ST7789 tft = Adafruit_ST7789(TFT_CS, TFT_DC, TFT_RST);

// Power management. After a button press, stay awake for DISPLAY_IDLE_COUNTER_RESET
// seconds. After a sensor high interupt, stay awake for SENSOR_IDLE_COUNTER_RESET 
// seconds.
#define SENSOR_IDLE_COUNTER_RESET 30
#define DISPLAY_IDLE_COUNTER_RESET 240
volatile int idleCounter = SENSOR_IDLE_COUNTER_RESET;

// We use this digital in for the trail user sensor active detection. This can change,
// but it needs to be a GPIO that has RTC functionality.
#define SENSOR_IN 12

// Chip select for the microSD card
#define SD_CARD_SELECT 10

// Slots for user counts
RTC_DATA_ATTR int totalSinceStart = 0;
RTC_DATA_ATTR int totalThisDay = 0;
RTC_DATA_ATTR int totalThisHour = 0;
RTC_DATA_ATTR int hourTrip = -1;
RTC_DATA_ATTR int dayTrip = -1;

// Slots for current sensor events
RTC_DATA_ATTR boolean sensorEnabled = true;
volatile unsigned long sensorEventStartTime = 0;
volatile unsigned long sensorEventDuration = 0;

// slots for the event log file
File logfile;
RTC_DATA_ATTR boolean recordingEvents = false;
RTC_DATA_ATTR char logFileName[20];

volatile int buttonPressed = 0;
#define UP_BUTTON 1
#define SELECT_BUTTON 2
#define DOWN_BUTTON 3

int activePage = 0;
#define MENU_PAGE 1
#define DASHBOARD_PAGE 2
#define SD_PAGE 3
#define SET_CLOCK_PAGE 4

int menuItemSelected = 1;
#define DASHBOARD_MENUITEM 1
#define SENSOR_MENUITEM 2
#define SD_MENUITEM 3
#define RESET_MENUITEM 4
#define SETCLOCK_MENUITEM 5
#define MAX_MENUITEM 5

int setClockLabelSelected = 0;
int setClockValueSelected = -1;
int setClockValues[5];
const String setClockLabels[6] = {"Year:","Month:","Day:","Hour:","Minute:","Save"};
const int setClockValuesMin[5] = {23,1,1,0,0};
const int setClockValuesMax[5] = {99,12,31,23,59};

//
// Interupt routine called when a proximity sensor event occurs. At the
// start of the event we'll remember the start time and at the end we'll
// compute the length of the duration, which will be a trigger to record
// the event to the SD card in the main loop. 
//
void onSensorChanged() {
  if (sensorEnabled) {
    if (digitalRead(SENSOR_IN) == HIGH) {
      sensorEventStartTime = millis();
      sensorEventDuration = 0;
    } else {
      if (sensorEventStartTime != 0) {
        sensorEventDuration = millis() - sensorEventStartTime;
        sensorEventStartTime = 0;
      }
    }
  }
  if (idleCounter < SENSOR_IDLE_COUNTER_RESET) {
    idleCounter = SENSOR_IDLE_COUNTER_RESET;
  }
}

//
// Interupt routine called whenever a button is pressed. Too much work to
// do in an interupt routine so if a button is pressed we'll note it for 
// the next loop iteration.
//
// On the reverse TFT feather board, D0 is normally high, D1, D2 are normally
// low.
//
void onButtonPressed() {

  // Debounce buttons
  static unsigned long last_interupt_time = 0;
  unsigned long interupt_time = millis();
  if (interupt_time - last_interupt_time > 300) {

    if (digitalRead(0) == LOW) {
      buttonPressed = UP_BUTTON;
      idleCounter = DISPLAY_IDLE_COUNTER_RESET;
    }
    if (digitalRead(1) == HIGH) {
      buttonPressed = SELECT_BUTTON;
      idleCounter = DISPLAY_IDLE_COUNTER_RESET;
    }
    if (digitalRead(2) == HIGH) {
      buttonPressed = DOWN_BUTTON;
      idleCounter = DISPLAY_IDLE_COUNTER_RESET;
    }
  }
  last_interupt_time = interupt_time;
}

void setup() {

  Serial.begin(115200);

  // We can get here either by a normal reset startup or by waking up from a deep sleep.
  // When in deep sleep, memory and connections can be lost so they need to be re-established,
  // but we don't want the verbose UI startup dialog or delays when waking
  boolean coldStart = true;
  switch(esp_sleep_get_wakeup_cause()) {
    case ESP_SLEEP_WAKEUP_EXT0 : coldStart = false; break;
    case ESP_SLEEP_WAKEUP_EXT1 : coldStart = false; break;
  }

  // If this is a wakeup from a sensor or button, we can't expect that the interupt 
  // routine was run (since we haven't called attach to interrupt yet). So call them
  // explicitly. This is non-destructive if an event or button press hadn't happened.
  if (!coldStart) {
    buttonPressed = 0;
    onButtonPressed();
    sensorEventStartTime = 0;
    onSensorChanged();
  }
  
  // set LED to be an output pin
  pinMode(LED_BUILTIN, OUTPUT);
  digitalWrite(LED_BUILTIN, LOW);

  // We won't use the NeoPixel
  pinMode(NEOPIXEL_POWER, OUTPUT);
  digitalWrite(NEOPIXEL_POWER, LOW);

  // Setup the TFT Display
  pinMode(TFT_BACKLITE, OUTPUT);
  pinMode(TFT_I2C_POWER, OUTPUT);
  tftOn();
  tft.init(135, 240); // Init ST7789 240x135
  tft.setRotation(3); // landscape mode with buttons on left
  tft.fillScreen(ST77XX_BLACK);

  // Start the startup splash screen
  tft.setCursor(0, 0);
  tft.setTextColor(ST77XX_WHITE);
  tft.setTextSize(2);
  if (coldStart) {
    tft.println("Nifty Counter");
    tft.println("version 1.0");
    tft.setTextSize(1);
    tft.println("\nCopyright (c) 2023 Loren Konkus\n");
  }

  // Initialize the RTC
  if (! rtc.begin()) {
    tft.setTextColor(ST77XX_RED);
    tft.setTextSize(2);
    tft.println("Fatal Error");
    tft.println("No Real Time Clock");
    Serial.println("Couldn't find RTC");
    Serial.flush();
    while (1) delay(10);
  }
  if (! rtc.initialized() || rtc.lostPower()) {
    Serial.println("RTC is NOT initialized, setting the time");
    // When time needs to be set on a new device, or after a power loss, the
    // following line sets the RTC to the date & time this sketch was compiled
    rtc.adjust(DateTime(F(__DATE__), F(__TIME__)));
    tft.setTextColor(ST77XX_YELLOW);
    tft.setTextSize(1);
    tft.println("Real Time Clock initialized");
  }   
  rtc.start();
  
  if (coldStart) {
    tft.setTextColor(ST77XX_GREEN);
    tft.setTextSize(1);
    tft.print("\nCurrent time: ");
    tft.setTextColor(ST77XX_WHITE);
    tft.println(getTimestampString(getCurrentTime()));
  }

  // Initialize the battery monitor
  if (!batteryMonitor.begin()) {
    tft.setTextColor(ST77XX_RED);
    tft.setTextSize(1);
    tft.println("Battery monitor not available");
  } else {    
    if (coldStart) {
      delay(1000); // battery monitor needs a moment to collect itself... 
      tft.setTextColor(ST77XX_GREEN);
      tft.setTextSize(1);
      tft.print("\nBattery Status: ");
      tft.setTextColor(ST77XX_WHITE);
      tft.print(batteryMonitor.cellVoltage(),1);
      tft.print("v, ");
      tft.print(batteryMonitor.cellPercent(),0);
      tft.println("%");
    }
  }

  // Initialize the SD card
  pinMode(SD_CARD_SELECT, OUTPUT);
  if (!SD.begin(SD_CARD_SELECT)) {
    tft.setTextColor(ST77XX_RED);
    tft.setTextSize(2);
    tft.println("Insert SD Card and");
    tft.println("press reset to");
    tft.println("proceed.");
    while (1) delay (1000);
  }

  // create an event log .csv file using the counter startup date
  boolean newfile = false;
  if (true) {
    eventsFileName(logFileName, getCurrentTime());
    if (!SD.exists(logFileName)) {
      newfile = true;
    }
    tft.setTextSize(1);
    tft.setTextColor(ST77XX_GREEN);
    if (newfile) {
      tft.print("\nCreating file: ");
    } else {
      tft.print("\nOpening file: ");
    }
    tft.setTextColor(ST77XX_WHITE);
    tft.println(logFileName);
  }

  logfile = SD.open(logFileName, "a+");
  if (!logfile) {
    tft.setTextColor(ST77XX_RED);
    tft.setTextSize(2);
    tft.println("Error opening log");
    tft.print("file. Check SD card");
    while (1) delay (1000);
  }
  recordingEvents = true;

  if (newfile) {
    logfile.println("Event Time, Duration, Event Count, Hour Count, Day Count, Cummulative Count");
    logfile.flush();
  }

  // Proximity detector digital in
  pinMode(SENSOR_IN, INPUT);
  attachInterrupt(digitalPinToInterrupt(SENSOR_IN), onSensorChanged, CHANGE);
  
  // Buttons
  pinMode(0, INPUT_PULLUP);
  pinMode(1, INPUT_PULLDOWN);
  pinMode(2, INPUT_PULLDOWN);
  attachInterrupt(digitalPinToInterrupt(0), onButtonPressed, FALLING);
  attachInterrupt(digitalPinToInterrupt(1), onButtonPressed, RISING);
  attachInterrupt(digitalPinToInterrupt(2), onButtonPressed, RISING);

  // We'll go into light sleep mode to save power between events. We'll wake up
  // for either a sensor input or a button press. Note that we don't wake for button
  // 0 presses - that's normally high button so it would wake us immediately.
  #define BUTTON_PIN_BITMASK 0x000001006 // io GPIO 1,2,12 in hex
  esp_sleep_enable_ext1_wakeup(BUTTON_PIN_BITMASK,ESP_EXT1_WAKEUP_ANY_HIGH);
  esp_sleep_pd_config(ESP_PD_DOMAIN_RTC_PERIPH, ESP_PD_OPTION_ON);
  rtc_gpio_pullup_en(GPIO_NUM_0);
  rtc_gpio_pulldown_en(GPIO_NUM_1);
  rtc_gpio_pulldown_en(GPIO_NUM_2);

  // Initialization complete
  if (coldStart) {
    tft.setTextColor(ST77XX_GREEN);
    tft.setTextSize(1);
    tft.println("\nStartup Successful");
    delay (5000);
  }
  
  activePage = 0;
  displayDashboardPage();
}

//
// Running mode
//
void loop() {

  // Manage the timeout. If we've gone DISPLAY_IDLE_COUNTER_RESET loops without
  // a button press, turn off the display. Users can press any button to turn it on again.
  if (idleCounter>0) {
    idleCounter--;
  }
  if (idleCounter == 0 &&
      sensorEventDuration == 0 &&
      sensorEventStartTime == 0) {
    // Idle time expired and we're not in the middle of processing an event, so close up
    // files and enter a deep sleep.
    if (logfile) {
      logfile.flush();
      logfile.close();
      delay(2000);
    }
    tftOff();
    esp_deep_sleep_start();
  } else {
    tftOn();
  }

  // If there was a button pressed, then take some action in the UI. UIs are messy - this is about
  // as complicated as I'd want to build before moving to a finite state machine
  if (buttonPressed != 0) {
    switch (activePage) {
      
      case DASHBOARD_PAGE:
        switch (buttonPressed) {
          
          case SELECT_BUTTON:
            displayMenuPage();
            break;
        }
        break;
      
      case SD_PAGE:
        switch (buttonPressed) {
          
          case SELECT_BUTTON:
            if (doLoadSDCard()) {
              displayMenuPage();
            }
            break;
        }
        break;
      
      case SET_CLOCK_PAGE:
        switch (buttonPressed) {
          
          case UP_BUTTON:
            if (setClockLabelSelected >= 0) {
              if (--setClockLabelSelected < 0) {
                setClockLabelSelected = 5;
              }
            }
            if (setClockValueSelected >= 0) {
              if (++setClockValues[setClockValueSelected] > setClockValuesMax[setClockValueSelected]) {
                setClockValues[setClockValueSelected] = setClockValuesMin[setClockValueSelected];
              }
            }
            break;
                   
          case DOWN_BUTTON:
            if (setClockLabelSelected >= 0) {
              if (++setClockLabelSelected > 5) {
                setClockLabelSelected = 0;
              }
            }
            if (setClockValueSelected >= 0) {
              if (--setClockValues[setClockValueSelected] < setClockValuesMin[setClockValueSelected]) {
                setClockValues[setClockValueSelected] = setClockValuesMax[setClockValueSelected];
              }
            }
            break;
                    
          case SELECT_BUTTON:
            if (setClockLabelSelected == 5) {
              doUpdateClock();
              displayMenuPage();
              break;
            }
            if (setClockLabelSelected >= 0) {
              setClockValueSelected = setClockLabelSelected;
              setClockLabelSelected = -1;
              break;
            }
            if (setClockValueSelected >= 0) {
              setClockLabelSelected = setClockValueSelected + 1;
              setClockValueSelected = -1;
            }
            break;
        }
        break;
      
      case MENU_PAGE:
        switch (buttonPressed) {
          
          case UP_BUTTON:
            if (--menuItemSelected < 1) {
              menuItemSelected = MAX_MENUITEM;
            }
            break;
                    
          case DOWN_BUTTON:
            if (++menuItemSelected > MAX_MENUITEM) {
              menuItemSelected = 1;
            }
            break;
         
          case SELECT_BUTTON:
            switch (menuItemSelected) {
            
              case DASHBOARD_MENUITEM:
                displayDashboardPage();
                break;
                
              case SENSOR_MENUITEM:
                doToggleSensors();
                break;
                
              case SD_MENUITEM:
                doRemoveSDCard();
                break;
                
              case RESET_MENUITEM:
                doResetCounters();
                break;
                
              case SETCLOCK_MENUITEM:
                displaySetClock();
                break;
            }
            break;
         
        }
        break;
    }
    buttonPressed = 0;
  }
  
  // Refresh the active page
  switch (activePage) {
    case MENU_PAGE:
      displayMenuPage();
      break;
    case SD_PAGE:
      doRemoveSDCard();
      break;
    case SET_CLOCK_PAGE:
      displaySetClock();
      break;
    case DASHBOARD_PAGE:
      displayDashboardPage();
      break;
  }
  
  //
  // Reset the hourly and daily counters if needed
  //
  DateTime now = getCurrentTime();
  if (now.day() != dayTrip) {
    totalThisDay = 0;
    dayTrip = now.day();
    totalThisHour = 0;
    hourTrip = now.hour();
  }
  if (now.hour() != hourTrip) {
    totalThisHour = 0;
    hourTrip = now.hour();
  }

  //
  // If an event occured, record it. The duration of the last event is a flag to
  // denote one occured.
  //
  if (sensorEventDuration != 0) {
    if (recordingEvents) {
      totalSinceStart++;
      totalThisDay++;
      totalThisHour++;
      String eventLogRecord = getTimestampString(now);
      eventLogRecord += ",";
      eventLogRecord += sensorEventDuration;
      eventLogRecord += ",1,";
      eventLogRecord += totalThisHour;
      eventLogRecord += ",";
      eventLogRecord += totalThisDay;
      eventLogRecord += ",";
      eventLogRecord += totalSinceStart;
      logfile.println(eventLogRecord);
      logfile.flush();
    }
    
    sensorEventDuration = 0;
  }

  delay(1000);               // wait for a second
}

//
// Get the current time
//
DateTime getCurrentTime() {
  return rtc.now();
}

//
// Get a time string in format mm-dd-yy hh:mm:ss, which seems to make 
// most spreadsheets happy. RTCs vary and may or may not support 4 digit dates,
// so we always just use last 2 for consistency.
//
String getTimestampString(DateTime aTime) {
  int thisYear = aTime.year();
  if (thisYear > 2000) {
    thisYear = thisYear - 2000;
  }
  char buffer[20];
  sprintf(buffer,"%02d-%02d-%02d %02d:%02d:%02d",aTime.month(),aTime.day(),thisYear,aTime.hour(),aTime.minute(),aTime.second());
  return String(buffer);
}

//
// Compute a FAT filename for the events log
//
void eventsFileName(char* buffer, DateTime aTime) {
  int aYear = aTime.year();
  if (aYear > 2000) {
    aYear = aYear - 2000;
  }
  sprintf(buffer,"/C%02d%02d%02d.csv",aYear,aTime.month(),aTime.day());
}

//
// Routine to turn on the TFT display. 
//
void tftOn() {
  digitalWrite(TFT_BACKLITE, HIGH);
  digitalWrite(TFT_I2C_POWER, HIGH);  
}

//
// Turn off the TFT display backlight and I2C power supply. There's a timer so when not 
// in use the display is turned off to save power
//
void tftOff() {
  digitalWrite(TFT_BACKLITE, LOW);
  digitalWrite(TFT_I2C_POWER, LOW);
}

// 
// User requested that the sensors be enabled or disabled
//
void doToggleSensors() {

  // change the sensor enable to whatever it isn't
  sensorEnabled = !sensorEnabled;

  // tell the user
  tft.fillScreen(ST77XX_BLACK);
  tft.setCursor(30, 60);
  tft.setTextColor(ST77XX_WHITE, ST77XX_BLACK);
  tft.setTextSize(2);
  if (sensorEnabled) {
    tft.print("Sensors enabled");
  } else {
    tft.print("Sensors offline");
  }
  delay (5000);
  tft.fillScreen(ST77XX_BLACK);
}

// 
// User requested that counters be reset to 0
//
void doResetCounters() {

  // reset counters
  totalSinceStart = 0;
  totalThisDay = 0;
  totalThisHour = 0;

  // tell the user
  tft.fillScreen(ST77XX_BLACK);
  tft.setCursor(30, 60);
  tft.setTextColor(ST77XX_WHITE, ST77XX_BLACK);
  tft.setTextSize(2);
  tft.print("Counters reset");
  delay (5000);
  tft.fillScreen(ST77XX_BLACK);  
}

// 
// User wants to update the date and time
//
void displaySetClock() {
  if (activePage != SET_CLOCK_PAGE) {
    DateTime aTime = getCurrentTime();
    setClockValues[0] = aTime.year();
    if (setClockValues[0] > 2000) {
      setClockValues[0] = setClockValues[0] - 2000;
    }
    setClockValues[1] = aTime.month();
    setClockValues[2] = aTime.day();
    setClockValues[3] = aTime.hour();
    setClockValues[4] = aTime.minute();
  
    // Initial page display
    tft.fillScreen(ST77XX_BLACK);
    tft.drawChar(0, 0, 30, ST77XX_CYAN, ST77XX_BLACK, 2);
    tft.drawChar(0, 60, 15, ST77XX_CYAN, ST77XX_BLACK, 2);
    tft.drawChar(0, 125, 31, ST77XX_CYAN, ST77XX_BLACK, 2);
    tft.setCursor(30, 0);
    tft.setTextColor(ST77XX_WHITE);
    tft.setTextSize(2);
    tft.print("  Set Clock");
    
    setClockLabelSelected = 0;
    setClockValueSelected = -1;
    activePage = SET_CLOCK_PAGE;
  }
  
  // Display the dynamic content
  for (int i=0; i<6; i++) {
    displaySetClockLabel(i);
  } 
  for (int i=0; i<5; i++) {
    displaySetClockValue(i);
  }
}

//
// On the Set Clock page, display the label for one of the clock fields
//
void displaySetClockLabel(int item) {
  if (setClockLabelSelected == item) {
    tft.setTextColor(ST77XX_BLACK, ST77XX_GREEN);
  } else {
    tft.setTextColor(ST77XX_GREEN, ST77XX_BLACK);
  }
  tft.setCursor(30,25+item*17);
  tft.print(setClockLabels[item]);
}

//
// On the Set Clock page, display the current value of one of the clock fields
void displaySetClockValue(int item) {
  if (setClockValueSelected == item) {
    tft.setTextColor(ST77XX_BLACK, ST77XX_GREEN);
  } else {
    tft.setTextColor(ST77XX_GREEN, ST77XX_BLACK);
  }
  tft.setCursor(140,25+item*17);
  if (setClockValues[item]<10) {
    tft.print("0");
  }
  tft.print(setClockValues[item]);
}

//
// User of the Set Clock page has updated the time - set the RTC clock to reflect it
//
void doUpdateClock() {
  DateTime newTime = DateTime(setClockValues[0]+2000,setClockValues[1],setClockValues[2],setClockValues[3],setClockValues[4],0);
  rtc.adjust(newTime);
}

// 
// User requested that the SD card be dismounted so that they can replace it
//
void doRemoveSDCard() {

  if (recordingEvents) {
    if (logfile) {
      logfile.flush();
      logfile.close();
    }
    recordingEvents = false;
  }
  
  // tell the user
  tft.fillScreen(ST77XX_BLACK);
  tft.drawChar(0, 0, 30, ST77XX_CYAN, ST77XX_BLACK, 2);
  tft.drawChar(0, 60, 15, ST77XX_CYAN, ST77XX_BLACK, 2);
  tft.drawChar(0, 125, 31, ST77XX_CYAN, ST77XX_BLACK, 2);
  tft.setCursor(30, 10);
  tft.setTextColor(ST77XX_GREEN, ST77XX_BLACK);
  tft.setTextSize(2);
  tft.println("SD card can be");
  tft.setCursor(30, 30);
  tft.println("safely removed.");
  tft.setCursor(30, 60);
  tft.setTextColor(ST77XX_WHITE, ST77XX_BLACK);
  tft.println("Insert new ");
  tft.setCursor(30, 80);
  tft.println("formatted card");
  tft.setCursor(30, 100);
  tft.println("and press restart");
//  tft.println("and press *");
  activePage = SD_PAGE;
}
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

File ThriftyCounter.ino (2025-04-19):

/*
  ThriftyCounter - A low cost adafruit M0 adalogger feather based Trail Counter

  A low cost trail use counter using off the shelf hardware and 
  inexpensive, readily available microwave sensors that's appropriate when you
  just want to place a few counters out on trails in the forest and are able
  to visit them every month or two to switch batteries and harvest the SD card. 

  Required components:
  - adafruit M0 adalogger feather board
  - a microwave sensor. Tested using RCWL-0516 and HFS-DC06F, but similar devices should
    work. Really, any sensor that provides a high detection pulse should work.

  Time stamped trail use data is recorded in a .csv file on the SD card that can be 
  imported into a spreadsheet for data analysis. Each entry in the log file will have
  a timestamp and the duration of the event. The green LED on the feather is lit
  whenever the detection sensor is high. The red LED flashes once each time an event
  is written to the SD card, or multiple blinks to indicate a specific error condition:

  2 blinks = error, no RTC clock found
  3 blinks = error, no microSD card. Insert one to clear condition
  4 blinks = error, unable to write to a microSD card

  Copyright © 2023 Loren Konkus
 
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
  The above copyright notice and this permission notice shall be included in
  all copies or substantial portions of the Software.
 */

#include <Wire.h>
#include "RTClib.h"
#include <RTCZero.h>
#include <SPI.h>
#include <SD.h>
#include <ArduinoLowPower.h>

// Select which kind of real time clock we should use
//#define USE_RTCZERO_TIME
#define USE_DS3231_TIME
 
#if defined(ARDUINO_SAMD_ZERO) 
  // Required for Serial on Zero based boards
  #define Serial SERIAL_PORT_USBVIRTUAL
#endif

// We use this digital in for the microwave sensor active detection. This can
// change, but we'll sleep the processor to save power between count events so whatever 
// you choose needs to be able to wake the processor up
const int sensorIn = 11;

// The SD card interface is tied to output 4
const int cardSelect = 4;

// LEDs we use to communicate with humans
const int redLED = 13;
const int greenLED = 8;

boolean eventsLogged = false;
volatile unsigned long eventStartTime = 0;
volatile unsigned long lastEventDuration = 0;
volatile int idleCounter = 1000;
File logfile;

#if defined(USE_RTCZERO_TIME) 
  RTCZero rtc;    
#endif
#if defined(USE_DS3231_TIME) 
  RTC_DS3231 rtc;    
#endif

//
// Interupt routine called when a proximity sensor event occurs. At the
// start of the event we'll remember the start time and at the end we'll
// compute the length of the duration, which will be a trigger to record
// the event to the SD card in the main loop. During the event, the green
// LED will be lit. 
//
void onSensorChanged() {
  if (digitalRead(sensorIn) == HIGH) {
    eventStartTime = millis();
    lastEventDuration = 0;
    digitalWrite(greenLED, HIGH);
  } else {
    lastEventDuration = millis() - eventStartTime;
    eventStartTime = 0;
    digitalWrite(greenLED, LOW);
  }
  idleCounter = 100;
}

//
// the setup function runs once when you press reset or power the board
//
void setup() {
  // configure IO pins
  pinMode(sensorIn, INPUT);
  pinMode(greenLED, OUTPUT);
  pinMode(redLED, OUTPUT);
  pinMode(cardSelect, OUTPUT);

  // Initialize the RTC. 
  DateTime compileTime = DateTime(F(__DATE__), F(__TIME__));
  
#if defined(USE_RTCZERO_TIME)
  rtc.begin();    // Start the RTC
  rtc.setTime(compileTime.hour(), compileTime.minute(), compileTime.second());   // Set the time
  rtc.setDate(compileTime.day(), compileTime.month(), compileTime.year()-2000);    // Set the date
#endif
#if defined(USE_DS3231_TIME)
  if (!rtc.begin()) {
    fatalError(2);
  }
  if (rtc.lostPower()) {
    rtc.adjust(DateTime(F(__DATE__), F(__TIME__)));
  }
#endif

  // Initialize the SD card
  // No card indicated by three rapid red flashes
  while (!SD.begin(cardSelect)) {
    error(3);
    delay(3000);
  }
  
  // create an event log .csv file using the counter startup date
  char filename[14];
  getEventsFileName(getCurrentTime(), filename);
  boolean newfile = false;
  if (! SD.exists(filename)) {
    newfile = true;
  }

  logfile = SD.open(filename, FILE_WRITE); 
  if (!logfile) {
    fatalError(4);
  }

  if (newfile) {
    // New file, so write out the spreadsheet column headers
    logfile.println("Timestamp, Date, Time, Duration, Event Count");
  } else {
    // So this shouldn't be necessary with FILE_WRITE, but for whatever reason an existing file
    // is occasionally positioned at beginning when re-opened and all your hard earned counter
    // data is overwritten. This forces an append at end of file.
    logfile.seek(logfile.size());
  }

  // Ready for sensor interupts
  LowPower.attachInterruptWakeup(sensorIn, onSensorChanged, CHANGE);
}

// 
// Main loop where we record events
//
void loop() {

  //
  // Manage low power mode. If no events have occured in the last few moments, then enter a sleep
  // state to save power. If events were written to the SD card, flush the buffer to ensure they 
  // are written to the card. (Actual SD card updates are power expensive, so we don't do that on
  // every event).
  //
  if (idleCounter >  0 || eventStartTime != 0) {
    idleCounter--;
    if (idleCounter == 0) {
      if (eventsLogged) {
        digitalWrite(redLED, HIGH);
        logfile.flush();
        delay(400);
        digitalWrite(redLED, LOW);
        eventsLogged = false;
      }
      LowPower.deepSleep();
    }
  }

  //
  // If an event occured, record it. The duration of the last event is a flag to
  // denote one occured.
  //
  if (lastEventDuration != 0) {
    DateTime eventTime = getCurrentTime();
    char eventLogRecord[50];
    getTimestampString(eventTime, eventLogRecord);
    strcat(eventLogRecord, ",");
    getDateString(eventTime, &eventLogRecord[strlen(eventLogRecord)]);
    strcat(eventLogRecord, ",");
    getTimeString(eventTime, &eventLogRecord[strlen(eventLogRecord)]);
    strcat(eventLogRecord, ",");
    sprintf(&eventLogRecord[strlen(eventLogRecord)], "%lu", lastEventDuration);
    strcat(eventLogRecord, ",1");

    digitalWrite(redLED, HIGH);
    logfile.println(eventLogRecord);
    eventsLogged = true;
    digitalWrite(redLED, LOW);
    
    lastEventDuration = 0;
  }

  delay(100);
}

//
// Get the current time
//
DateTime getCurrentTime() {
#if defined(USE_RTCZERO_TIME) 
  return DateTime(rtc.getYear(),rtc.getMonth(), rtc.getDay(), rtc.getHours(), rtc.getMinutes(), rtc.getSeconds());
#endif
#if defined(USE_DS3231_TIME) 
  return rtc.now();
#endif
}

//
// Compute a FAT filename for the events log
//
// aTime - a DataTime object
// buffer - a char array of at least 14 chars to receive the filename
//
void getEventsFileName(DateTime aTime, char* buffer) {
  int aYear = aTime.year();
  if (aYear > 2000) {
    aYear = aYear - 2000;
  }
  sprintf(buffer,"C%02d%02d%02d.csv",aYear,aTime.month(),aTime.day());
}
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

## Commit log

2023-03-29 Initial load
    [FeatherComponentFrame.stl]
2023-04-06 Updated to support deep sleep power saving mode
2023-04-24 Add files via upload
    Don't sleep during long duration detection events
    Fix bug with occasionally overwriting SD data
    Minimize use of String objects to avoid potential memory issues
    [ThriftyCounter.ino]
2025-01-04 fix: if definition bracket breaks USE_RTZERO_TIME
    [ThriftyCounter.ino]
2025-04-18 Add files via upload
    STIL files for a 3d printed trail counter box tailored towards a NiftyCounter.
    [NiftyCounterBox.stl, NiftyCounterBoxLatch.stl, NiftyCounterBoxLid.stl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]
